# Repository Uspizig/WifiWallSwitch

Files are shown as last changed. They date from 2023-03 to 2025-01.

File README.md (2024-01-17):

A WallSwitch with a clever EINK Display that measures your Air Quality, measures Temperature, detects movement, measures Light Conditions... and many more.
And the Best of all: "It can be your own LOCAL Voice Assistant or MediaPlayer"

This Device perfectly integrates in your Smart Home (e.g. HomeAssistant or IO Broker).  
No permanent backlight On Display that disturbs your sleep. Just a brillant E-Ink Display with outstanding contrast and some Buttons that you can feel when you swipe over with your plam.
A lightweight Design with a perfect WAF Factor. Fits on your Desktop or on your wall. 
The device can be programmed, adapted, hacked, tinkered and individualised by YOU.
You want to push boundries even further: Use Arduino and do a deep Dive in Ultra Low Power Mode. The Battery might run for Years with an intelligent Power Gateing.

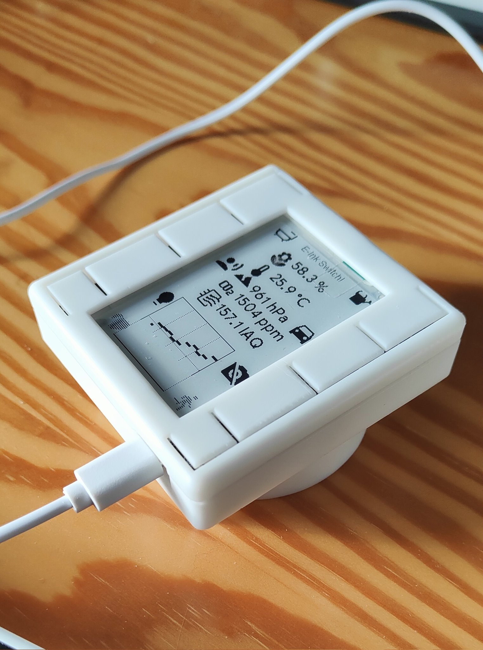
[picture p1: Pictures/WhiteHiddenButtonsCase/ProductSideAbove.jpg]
Side View of WifiWallSwitch with EINK Screen and Design Buttons. Ambient Light OFF Product View of WifiWallSwitch with disabled RGB LEDs


Eight Ambient Light LEDs can give you a visual quick feedback if needed:
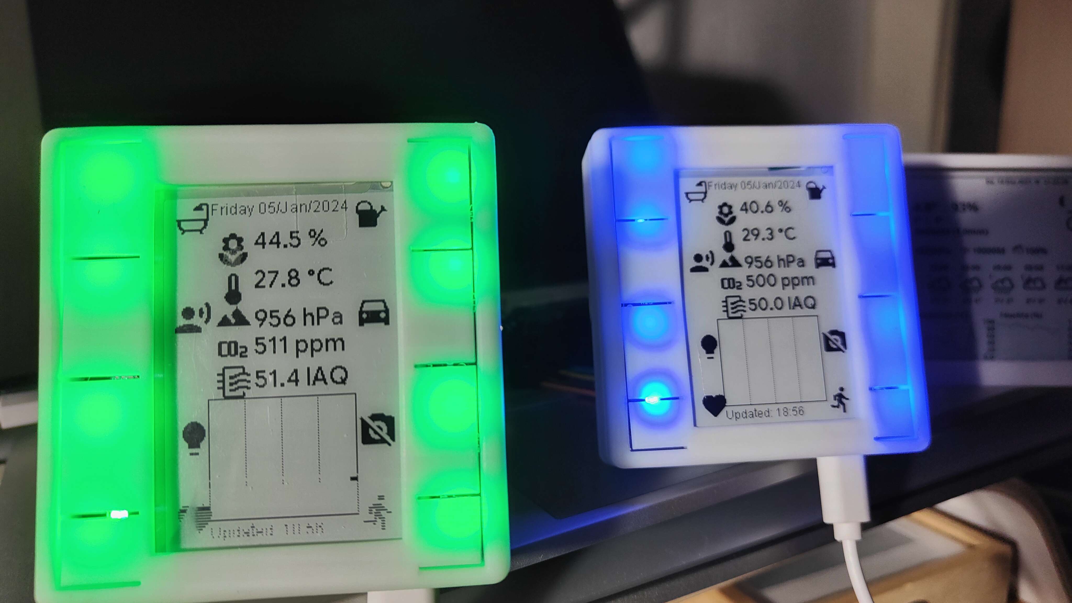
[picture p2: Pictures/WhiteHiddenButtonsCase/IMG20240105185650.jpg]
Side View of WifiWallSwitch with EINK Screen and Design Buttons. Ambient Light ON Product View of WifiWallSwitch with enabled RGB LEDs


View of the components in HomeAssistant
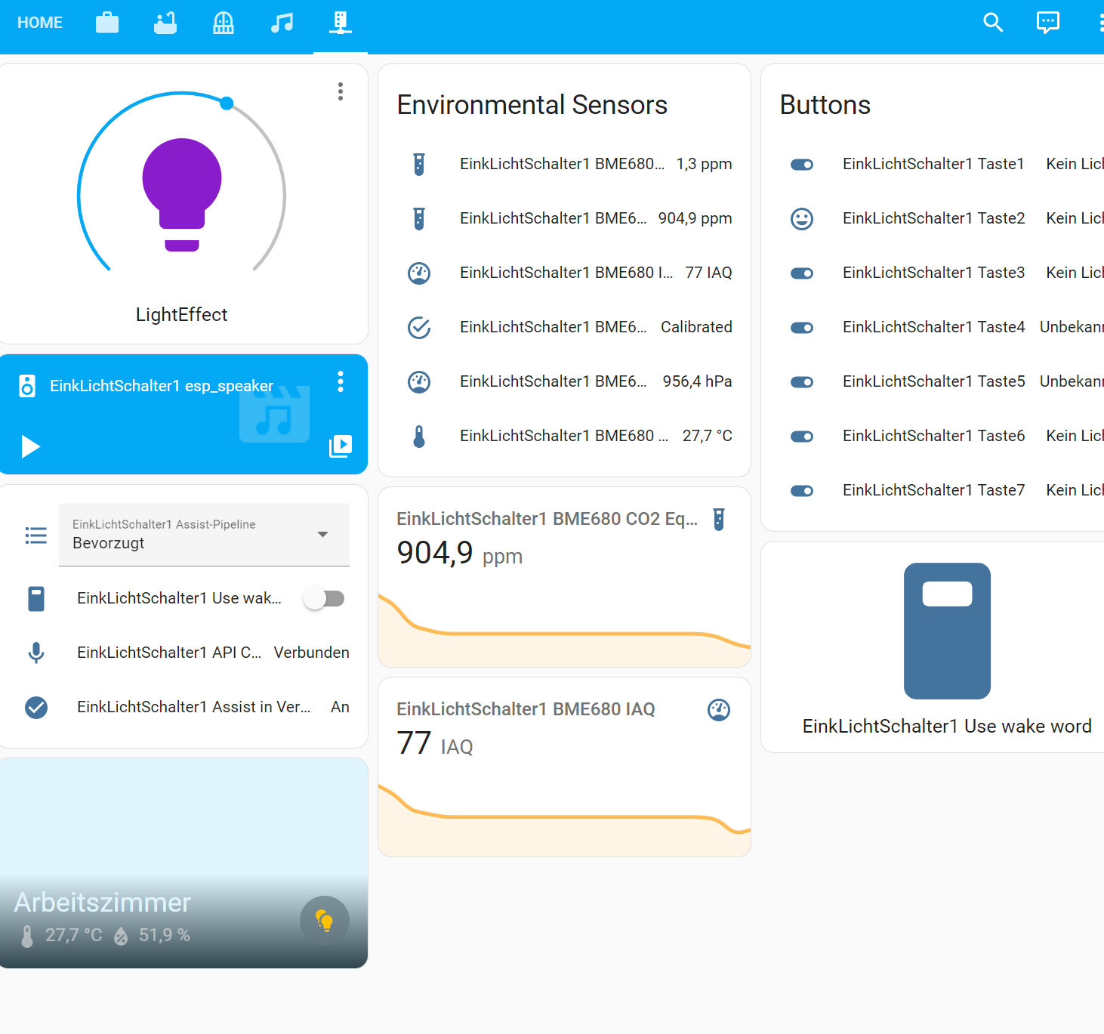
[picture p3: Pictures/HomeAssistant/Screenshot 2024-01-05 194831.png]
Side View of WifiWallSwitch with EINK Screen and Design Buttons. Ambient Light ON Product View of WifiWallSwitch with enabled RGB LEDs


What is under the hood:
Main thing you see when you have a first look is the massive 2.7 " E-Ink Screen
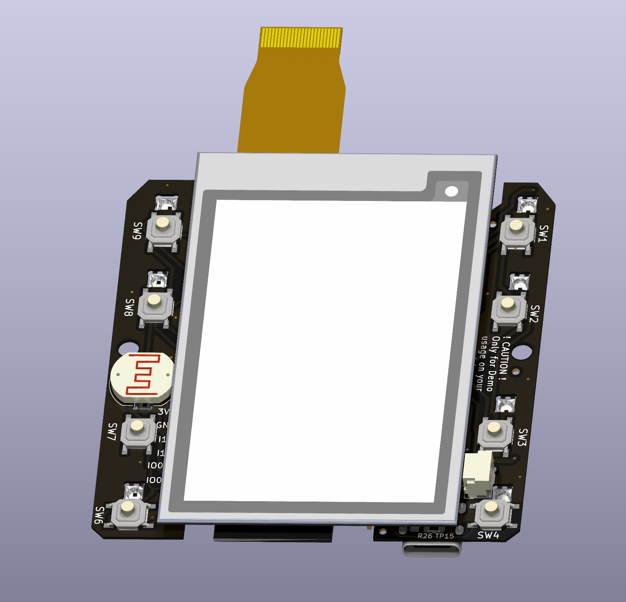
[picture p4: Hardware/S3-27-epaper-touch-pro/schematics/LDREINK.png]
Customer VIEW of PCB of WifiWallSwitch WiFiWallSwitch Customer side


See it in Action here: https://twitter.com/USpizig/status/1747731234338336940

Hardware Specs:
- 2.7" EInk Epaper with or without Touch Screen... other screens might work as well
- ESP32 S3 Dual Core Microcontroller with USB OTG, Wifi & BT, Mass Storage Mode. 
- 8 X SK6812 Mini RBG LEDs
- 8 X Hardware Buttons...REAL BUTTONS with clicks: No Touch Buttons that might not work if you have wet or dirty fingers
- BOSCH BME680 for eCo2, Temperature, Humidity and Pressure Measurements
- ST LSM6DSL Ultra Low Noise MEMS Gyro + Accel for Movement Detection and Earthquake Detection
- INMP441 MEMS Microphone for Voice Assistant
- Socket for MAX98357A I2S Class D Amplifier for Audio Output for Media Player
- LDR Ambient Light Sensor: Detect the Ambient Light conditions in your room.
- RTC1: TPL5110 for PowerGateing and low Standby Current
- RTC2 Option: RV3028 C7 for Ultra Low RTC with Backup Cap lasts 3h
- Optional: RFM95 LoRa Radio for Desaster Radio (Limitations: May not work together with Microphone)
- Connector for KNX EIB Smart Home with Nano BCU
- Connector for Your Own Ideas... Several free GPIOs
- Switch for adapting to Waveshare/Gooddisplay EINK Display
- All SMD components have a size 0603 or larger to enable easier soldering/Tinkering.

Underneath the EINK Screen is a placeholder for an optional RFM95/RFM98 Long Range Communication Module. This Module works with LoRa, FSK or other wireless standards. 
Up 15km Range of communication can be established with this module. Perfect as well for decoding your Bresser Weather Station and translate it to MQTT for your Smart Home.

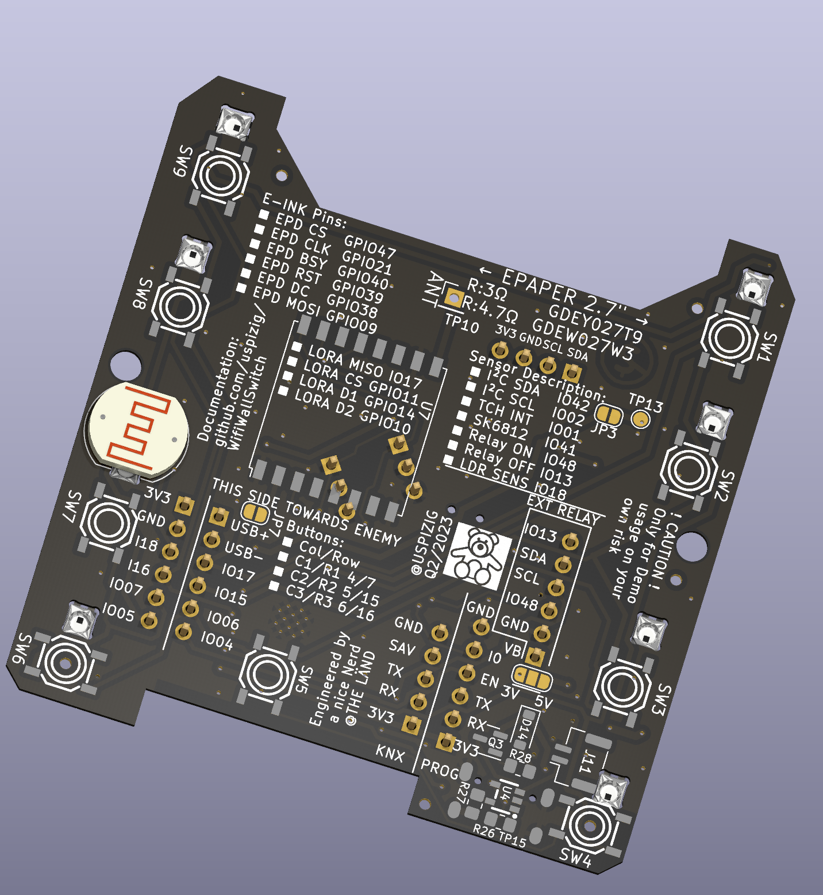
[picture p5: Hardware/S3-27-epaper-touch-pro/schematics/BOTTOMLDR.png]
PCB Customer View of WifiWallSwitch without EINK Screen


The other side of the PCB looks like this:
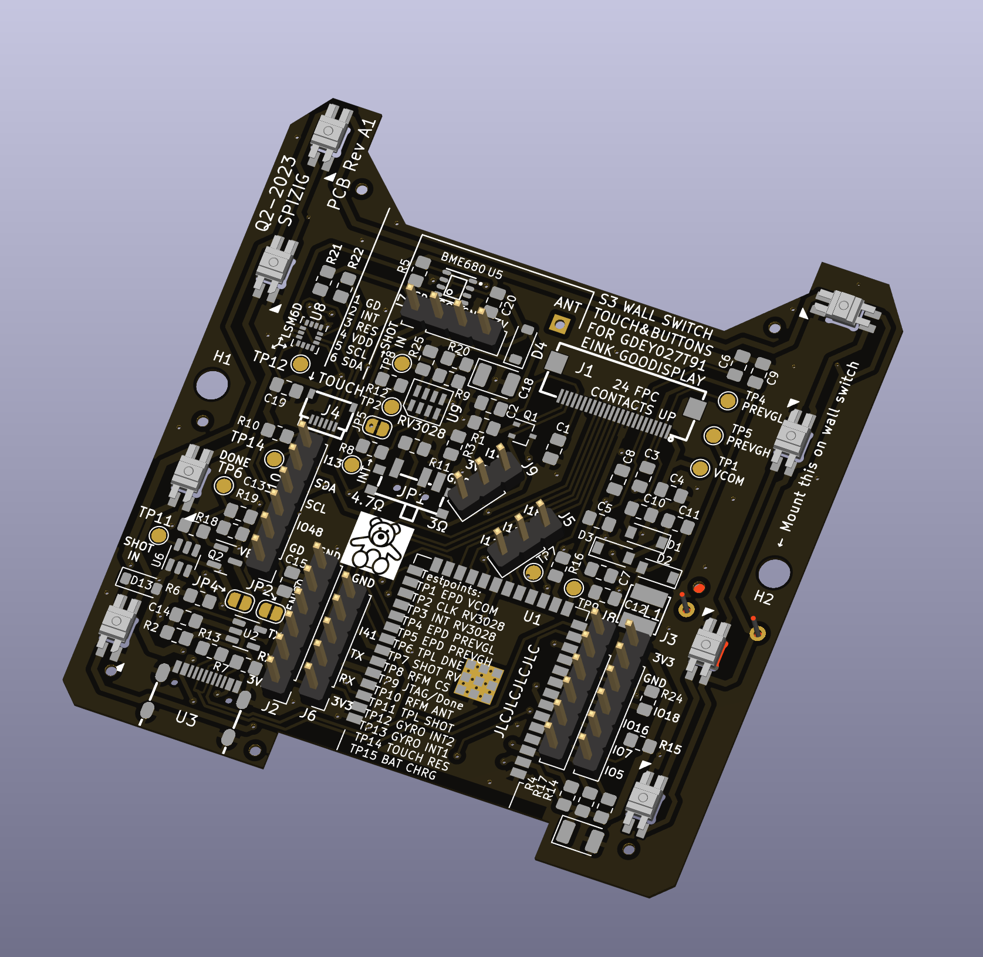
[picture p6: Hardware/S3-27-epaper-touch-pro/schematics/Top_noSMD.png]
Parts view of PCB without SMD parts soldered


If you scroll further down you may see a picture of the TOP View of the PCB
On the Top side of the PCB you see the Main Processor: This is an ESP32-S3 and various sensors:
- Ultra Low Power RTC RV3028 [U9] for Low Power Battery Operation wakeup
- Ultra Low Noise MEMS LSM6DSL [U8] 6 Axis GYRO+ACCEL + Tap Detection
- Ultra Low Power Gateing Chip TPL5110: [U6]
- Bosch BME680 for Air Quality Measurements [U5]
- EInk Screen connector 
- Touch Screen connector [JP5]
- Space for the oprional INMP441 Microphone [J5], [J9]
- 8 RGB LEDs which can be adressed individually. Perfect for Quizshow effects. Ideal for Audiovisual feeddback
- 9 Click Buttons. [SW1-SW9] - SW5 is hidden under the screen and can be used as Physical Click Button
- Space for Several Connectors[J2, J8, J3] to plugin even more modules like Audio Module for an Media Player or Voice Assistant Feedback.

And another view with all the SMD Parts simulated:
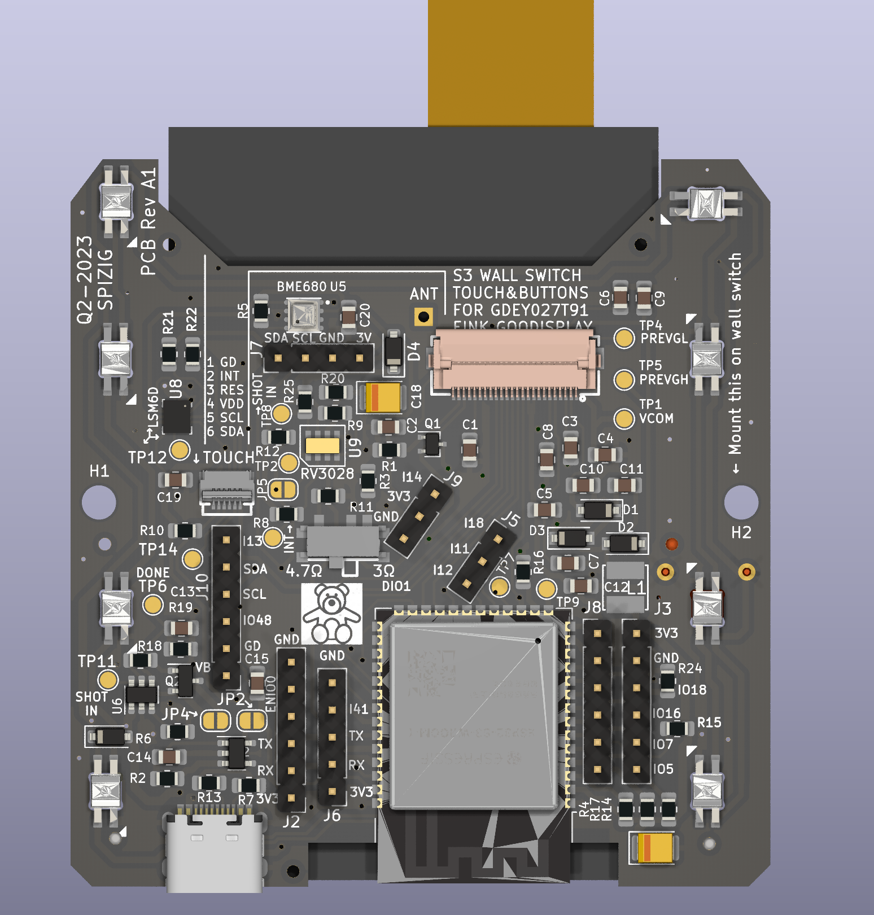
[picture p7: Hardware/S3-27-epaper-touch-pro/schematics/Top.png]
TOP PCB View of WifiWallSwitch


What is currently working:

Hardware:
- Currently the HW BringUp is about to finish.
- The basic Hardware is up and running stable.
- Eink, Microphone, LEDs, Buttons, BME680. LSM6 Gyro work well.

The optional Modules are  still under test
  -   TP4065 Lipo Battery Charger Circuit
  -   Battery Switchover Circuit once Battery is fully charged to avoid Battery damage due to overcharging
  -   TPL5110 Low Power RTC Module
  -   RV3028 Low Power Module
  -   Long Range Communication Module RF Module RFM95
  -   230V Power Converter to 5V/3.3V for Wall Mode.

Software Sketches working:
Arduino:
  - Flashing the Device over USB with you Chrome Web Browser: https://web.esphome.io/
  - Logging over USB USBSerial
  - EInk Basic Update of content
  - EInk Partial Update Dynamic Update of content
  - Read out BME680 Data (Temp, Humidity, Pressure, eCO2, IAQ,...)
  - Microfone: Calculate loudness in dBA
  - Audio Player: Playback MP3, TTS via Google and Webradio
  - 8 Buttons can be detected.
  - 8 RGB LEDS whcih can be adressed individually
  - LSM6 Gyro: Read out of Basic Values Roll, Pitch, Yaw
  - All typical 24pin EInk Displays which are mentioned on GxEPD2: https://github.com/ZinggJM/GxEPD2/tree/master
  - Flashing & Logging the Device over 2.54mm Socket with a dedicated Flash Adapter

 Home Assistant with ESPHome Integration:
   - Flashing the Device over USB with you Chrome Web Browser: https://web.esphome.io/
   - Logging over USB with ESP Home
   - Display Messages on EInk Display
   - Voice Assistant: Switch on Light,.... you name it
   - Media Player: Playback of TTS Messages, Audio Files,Web Radio
   - Keyboard: 8 Buttons are detected individulally
   - RGB LED Control SK6812 Mini
   - Flashing & Logging the Device over 2.54mm Socket with a dedicated Flash Adapter
     
Known ESPHome Issues right now:
  - Voice Assistant has some issues if used together with Media Player. Leads to Stuttering Audio once Media Playback is started.
  - No LSM GYRO integration
  - 2 GPIOS used to much due to Keypad component of ESPhome only supports 4x4 Matrix Keyboards
  - GPIO8 can not be used for Keyboard Fake Keys.

Known Issues on Arduino:
  - LSM6 Gyro has some issues with BME680 BSEC: Leads to constant output of 500 ppm

What is planned:
- EInk Touch Screen 2.7 'integration of Good Display https://www.good-display.com/product/259.html
- A Touch screen https://www.good-display.com/product/259.html
- Read out data of a Weather Station Bresser 6in1 We<ther Station and forward to MQTT with an RFM95 Chip.
- LDR for Light Detection. Monitoring of Enviroment Data
- Ultra Low Power RTC RV3028 for Low Power Battery Operation wakeup
- Ultra Low Noise MEMS LSM6DSL GYRO+ACCEL for Earthquake Detection-> https://github.com/biagiom/QuakeSense
- Ultra Low Noise MEMS LSM6DSL for movement detection and Tap Detection
- Ultra Low Power Mode TPL5110: Let the Processor sleep with TPL5110 Power Gateing and shut down all that is battery draining.
- Bosch BME680 for Air Quality Measurements
- 9 physical buttons for moments where you do not wnat to use a touchscreen
- KNX Integraion with Nano BCU
- LORA:
  - Transmit Air Quality Data on a regular Basis (every 15min)
  - Transmit Data when Air Quality changes dramatically
  - Transmit Data when Air Quality changes dramatically
  - Recieve Commands to Switch on / off ext Relay
  - Switch to Desaster Mode and search for BLE Heart Rate Devices nearby and sent this data via LoRa

WARNINGS
This is my hobby. Please do NOT be a DIRTY COPY CAT and make your own comercial product out of it.
See License before you copy anything out of it.
 
If you use this Hardware, Software, Code or schematics you agree that any harm, damage, burn or injuries are YOUR RESPONSIBILITY! 
The Author may not be held liable for any damage that might happen if you try this code out or use this product or parts of it.
Legal validity of this disclaimer: This disclaimer is to be regarded as part of the internet publication which you were referred from. 
If sections or individual terms of this statement are not legal or correct, the content or validity of the other parts remain uninfluenced by this fact.

Referrals and links The author is not responsible for any contents linked or referred to from his pages - unless he has full knowledge of illegal contents and would be able to prevent the visitors of his site from viewing those pages. If any damage occurs by the use of information presented there, the author might not be liable. Furthermore the author is not liable for any postings or messages published by users of discussion boards, guest books or mailing lists provided.

Arduino:
Before you compile please ensure you modify all your credentials and used sensors in "credentials.h" which have been marked REPLACEMEUSER
This Source Code is provided "AS it is" . 
Also ensure you have installed the following libs:
Code Sources that influenced this Source Code and which libaries you may need:

https://github.com/knolleary/pubsubclient/blob/master/examples/mqtt_auth/mqtt_auth.ino
https://randomnerdtutorials.com/esp32-mqtt-publish-subscribe-arduino-ide/
RGBW for SK6812:
Original code by Jim Bumgardner (http://krazydad.com).
Modified by David Madison (http://partsnotincluded.com).
Extended by Christoph Wempe
https://gist.github.com/CWempe?direction=desc&sort=created

Adafruit BME/BMP280/SGP30 sketches/libs
Please consider buying their products due to their great work in Arduino libs
https://github.com/adafruit/Adafruit_SGP30
https://github.com/adafruit/Adafruit_BMP280_Library

Bosch BME680 BSEC Lib
https://github.com/BoschSensortec/BSEC-Arduino-library

Andreas Spiess
OTA Sketch for OTA Update of the ESP32 over Wifi
https://github.com/SensorsIot/ESP32-OTA

Knolleary pubsubclient
/pubsubclient/blob/master/examples/mqtt_auth/mqtt_auth
https://github.com/knolleary/pubsubclient

Fastled
https://github.com/FastLED/FastLED

Settings for Jumpers & Solder Bridges:
Jumper:
- JP2 = This MUST BE OPEN! if USB Connected & 3.3V Prog
- JP3 = GYRO INT Emergency CUT: If you want no more Interupts from the Gyro.
- JP4 = MAINS Mode / No TPL5110 Mode. Disable the RTC for Power Gateing. Use for permanent connection to USB
- JP5 = RV3028 INT CUT for RFM95 OP. Must be cut if an RFM Long Range RF Mode is installed
- JP6 = Switch of Input Power Supply Voltage
- JP5 = Solder for RFM95 OP & Cut JP5

I²C Address of onboard Devices.
- 0x52 RV3028
- 0x6A LSM6DSL
- 0x77 BME680

Testpoints for soldering and Tinkering:
TP1 EPD VCOM -> Debuging of EINK
TP2 CLK RV3028 
TP3 INT RV3028
TP4 EPD PREVGL -> Debuging of EINK
TP5 EPD PREVGH -> Debuging of EINK
TP6 TPL DNE -> Debuging of EINK... Connect to a GPIO for Ulatra Low Power sleep and fire a 1 whenever you want to Deep Sleep on that GPIO
TP7 SHOT RV3028 -> Wakeup Pin for RTC2
TP8 RFM CS -> Soldering Pin needed for RFM95
TP9 JTAG/Done
TP10 RFM ANT -> Connector for 868 MHZ Antenna
TP11 TPL SHOT -> Wakeup Pin for TPL 5110 RTC
TP12 GYRO INT2
TP13 GYRO INT1
TP14 TOUCH RES -> Touch Controller Reset Pin. Hopefully never needed
TP15 BAT CHRG -> Battery charg Pin. Hopefully never needed.

Known HW Limitations:
- LDR is not working when WIFI is ON. Stupid ESP32-S3 Limitations ADC2 is not working if WIFi is on
- HW Buttons placed 90° wrong. Wrong Pinout matching

TODO:
- RV_3028 INT ist connected with LORA RFM MISO. No paralell usage possible
- INMP441 Mic ist connected with LORA RFM95. No paralell usage possible
- USB ESD Diodes missing
- SK6812 is an input of KNX connector at the same time?
- Rerouting of SK6812 necesssary. Not possible to  GPIO 0... otherwise board will not start.
- Done Pin TPL5110 not routed to ESP32 IO3. No Power Shutdown without a Solder Bridge
-

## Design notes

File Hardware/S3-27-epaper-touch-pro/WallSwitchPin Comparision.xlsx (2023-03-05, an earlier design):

PIN ESP32 S3 | PIN ESP32 | Function | ADC ESP32-S3 | ESP32
IO4 | IO36 | COL1 | ADC1 CH3 | ADC1 CH0
IO5 | IO39 | COL2 | ADC1 CH4 | ADC1 CH3
IO6 | IO34 | COL3 | ADC1 CH5 | ADC1 CH6
IO7 | IO35 | ROW1 | ADC1 CH6 | ADC1 CH7
IO15 | IO32 | ROW2 | ADC2 CH4 | ADC1 CH4
IO16 | IO33 | ROW3 | ADC2 CH5 | ADC1 CH5
IO17 | IO25 | MISO RFM95
IO18 | IO26 | Connector,
IO8 | IO27 | RTC_INT, GYRO INT
IO19 | IO14 | USB
IO20 | IO12 | USB
IO3 |  | UNUSED | STRAPING | NO USE
IO46 | GND | UNUSED | STRAPING | NO USE
IO9 | IO13 | MOSI EPD/RFM
IO10 | SHD | RFM95 DIO2 |  | NO USE
IO11 | SWP | RFM_CS |  | NO USE
IO12 | SCS | RFM95 DIO1 |  | NO USE
IO13 | SCK | RELAIS OFF |  | NO USE
IO14 | SDO | RFM95 RES |  | NO USE
IO21 | SD1 | EPD CLK |  | NO USE
IO47 | IO15 | EPD CS
IO48 | IO2 | Relais ON |  | STRAPING
IO45 |  | unused | STRAPING | NO USE
IO0 | IO0 | unused | STRAPING | STRAPING
IO35 | IO4 | unused | STRAPING
IO36 | IO16 | unused | STRAPING
IO37 | IO17 | unused | STRAPING
IO38 | IO5 | EPD_DC |  | STRAPING
IO39 | IO18 | EPD_RST
IO40 | IO19 | EPD_BUSY
IO41 | NC | SK6812_DATA
IO42 | IO21 | TOUCH_SDA
RX | RX
TXD0 | TXD0
IO2 | IO22 | Touch_SCL
IO1 | IO23 | Touch_INT

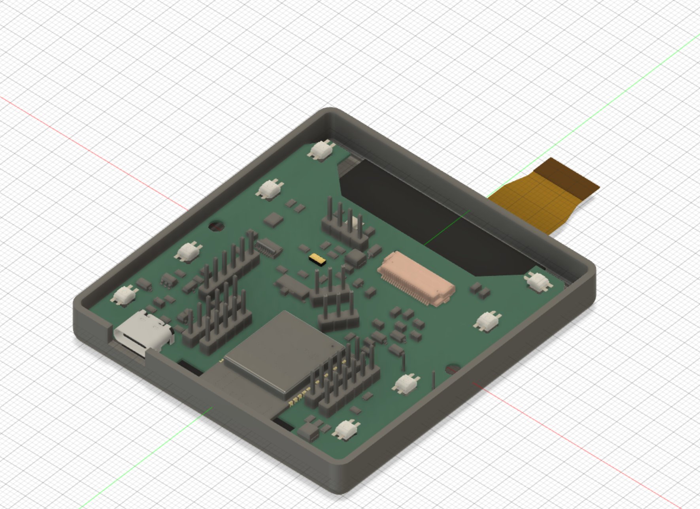
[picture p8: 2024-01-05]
Pictures/KiCad3DView/case bot.jpg

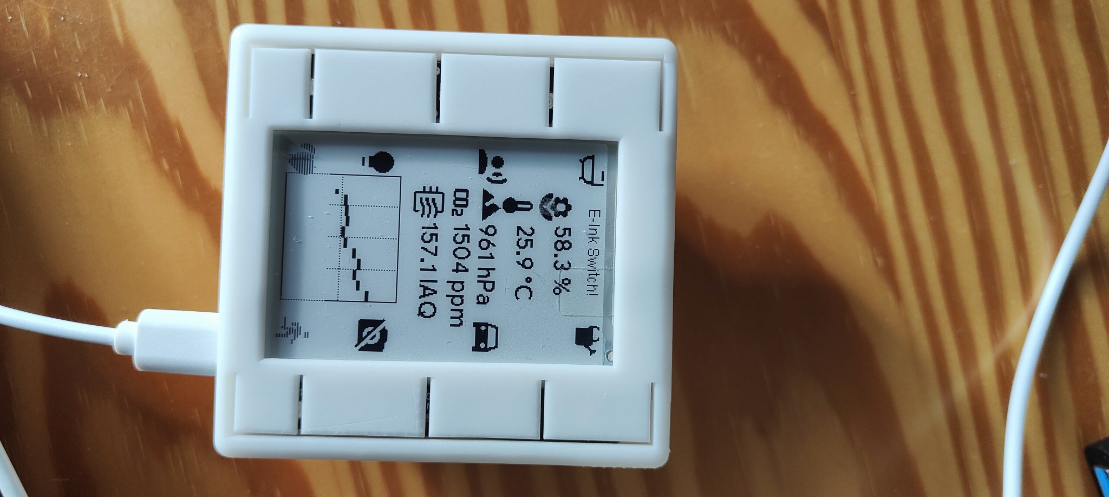
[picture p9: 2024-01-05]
Pictures/WhiteHiddenButtonsCase/topview.jpg

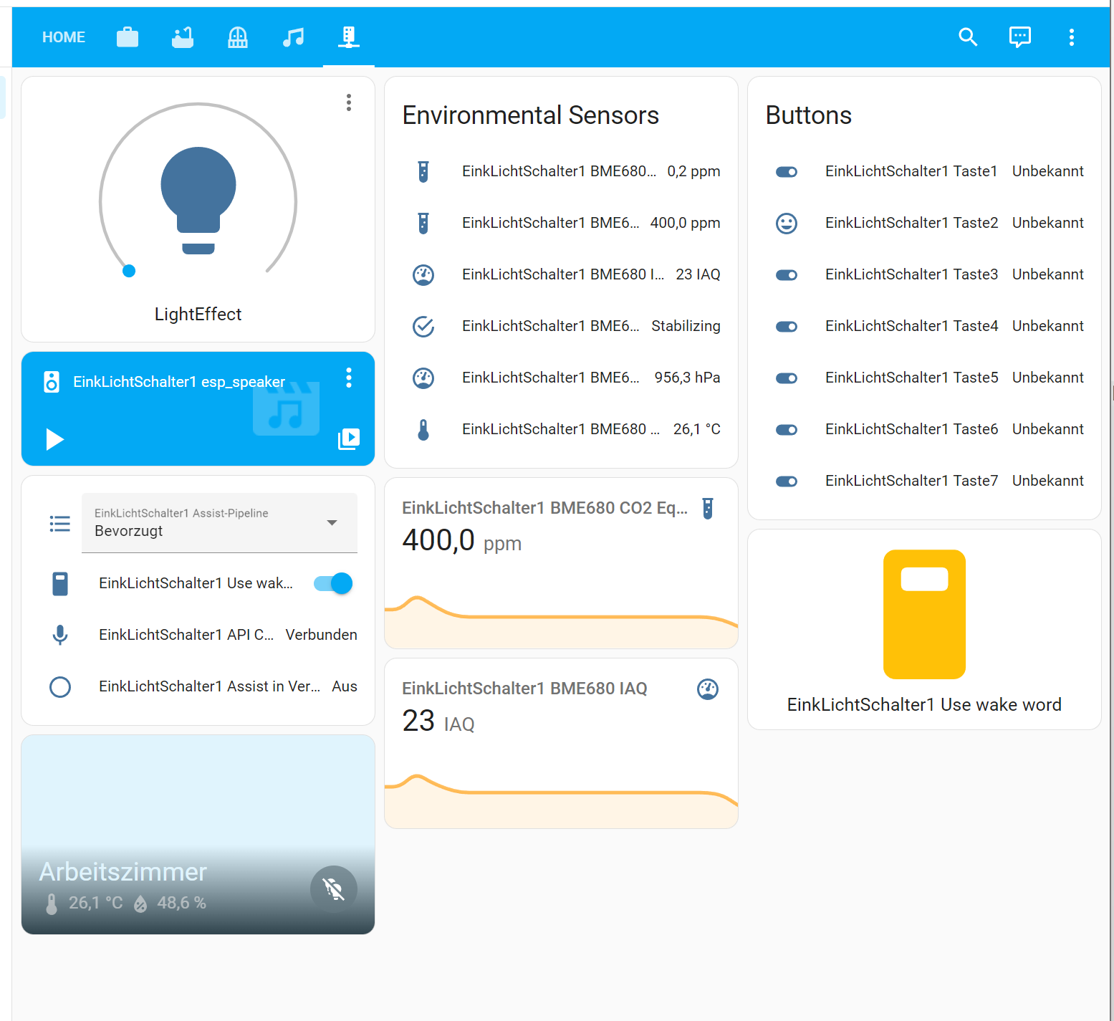
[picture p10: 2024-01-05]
Pictures/HomeAssistant/Screenshot 2024-01-05 184331.png

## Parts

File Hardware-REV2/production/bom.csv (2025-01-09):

Designator | Footprint | Quantity | Value | LCSC Part #
AE1 | U.FL_Molex_MCRF_73412-0110_Vertical | 1 | Antenna_Shield
C1, C14, C15, C16, C17, C2, C3, C4, C5, C6, C7, C8 | 0805 | 12 | 1uF | C28323
C10, C11, C12, C9 | 0805 | 4 | 4.7uF 50V_US | C162420
C13, C19, C20 | 0805 | 3 | 100nF | C49678
C18 | CP_EIA-3528-21_Kemet-B | 1 | 220uF
C21, C22, C26 | 0805 | 3 | 100nF
C23 | 0805 | 1 | 4u7F
C24 | 0805 | 1 | 220nF
C25 | 0603 | 1 | 100nF
D1, D13, D14, D2, D3, D4 | D_SOD-123 | 6 | MBR0530
D10, D11, D12, D5, D6, D7, D8, D9 | MX_SK6812MINI-E | 8 | SK6812MINI-E
H1, H2 | MountingHole_3.2mm_M3 | 2 | MountingSwitch
J1 | FPC-SMD_P0.50-24P_QCHF-SM-H2.0 | 1 | AFC24-S24FIC-00 | C262292
J10 | PinHeader_1x02_P2.00mm_Vertical | 1 | Conn_01x02_Pin
J11 | JST_GH_SM02B-GHS-TB_1x02-1MP_P1.25mm_Horizontal | 1 | Conn_01x02_Pin
J12 | PinHeader_1x07_P2.54mm_Vertical | 1 | Conn_01x07_Pin
J13 | TF-SMD_XKTF-0803-0 | 1 | Micro_SD_Card_Det_US
J2, J3, J8 | PinHeader_1x06_P2.54mm_Vertical | 3 | Conn_01x06
J4 | FFC-SMD_6P-P0.50_FH34SRJ-6S-0.5SH | 1 | TochConn | C224194
J5, J9 | PinHeader_1x03_P2.54mm_Vertical | 2 | Conn_01x03_Pin
J6 | PinHeader_1x05_P2.54mm_Vertical | 1 | Conn_01x05_Pin
J7 | PinHeader_1x04_P2.54mm_Vertical | 1 | Conn_01x04_Pin
JOG | JogWheel | 1 | jogdial
JP1 | SW-SMD_G-SWITCH_MK-12C02-G015 | 1 | RESE | C2911519
JP10 | SolderJumper-2_P1.3mm_Bridged_RoundedPad1.0x1.5mm | 1 | Jumper_2_Open
JP11, JP2, JP3, JP5 | SolderJumper-2_P1.3mm_Bridged_RoundedPad1.0x1.5mm | 4 | Jumper_2_Bridged
JP12, JP14, JP4, JP8 | SolderJumper-2_P1.3mm_Open_RoundedPad1.0x1.5mm | 4 | Jumper_2_Open
JP13, JP9 | SolderJumper-2_P1.3mm_Open_RoundedPad1.0x1.5mm | 2 | Jumper_2_Bridged
JP6, JP7 | SolderJumper-3_P1.3mm_Bridged12_RoundedPad1.0x1.5mm_NumberLabels | 2 | Jumper_3_Bridged12
L1 | IND-SMD_L4.0-W4.0 | 1 | 10uH
Q1 | SOT-323_SC-70 | 1 | Si1308
Q2, Q3 | SOT-23 | 2 | Si2301
R1, R10, R12, R14, R15, R17, R18, R19, R2, R25, R28, R4, R5, R8, R9 | 0805 | 15 | 10K | C17414
R11, R40 | 0805 | 2 | 0.47R
R13, R27, R7 | 0805 | 3 | 5k11 | C27834
R16, R24, R29, R30 | 0603 | 4 | N.C.
R20 | 0805 | 1 | N.C.
R21, R22 | 0805 | 2 | 0R | C17477
R23 | R_LDR_10x8.5mm_P7.6mm_Vertical | 1 | LDR03
R26 | 0805 | 1 | 800K
R3 | 0805 | 1 | 3R
R31 | 0805 | 1 | 100K
R32 | 0805 | 1 | 330k
R33 | 0603 | 1 | 100K
R34, R35, R36, R37, R38, R39 | 0603 | 6 | 10k
R6 | 0805 | 1 | 220K
SW1, SW2, SW3, SW4, SW5, SW6, SW7, SW8, SW9 | SW-SMD_4P-CORR-L5.2-W5.2-P3.70-LS6.4 | 9 | SW_Push
TP1, TP13, TP7, TP9 | TestPoint_Pad_D1.5mm | 4 | VCOM
TP10 | PinHeader_1x01_P2.54mm_Vertical | 1 | VCOM
TP11 | TestPoint_Pad_D1.5mm | 1 | SHOT
TP12 | TestPoint_Pad_D1.0mm | 1 | VCOM
TP14 | TestPoint_Pad_D1.5mm | 1 | RESET_TOUCH
TP15 | TestPoint_Pad_D1.0mm | 1 | M-
TP16 | TestPoint_Pad_D1.0mm | 1 | M+
TP2 | TestPoint_Pad_D1.5mm | 1 | CLKOUT
TP3 | TestPoint_Pad_D1.5mm | 1 | SHOT1
TP4 | TestPoint_Pad_D1.5mm | 1 | PREVGL
TP5 | TestPoint_Pad_D1.5mm | 1 | PREVGH
TP6 | TestPoint_Pad_D1.5mm | 1 | DONE
TP8 | TestPoint_Pad_D1.5mm | 1 | SHOT IN
U1 | ESP32-S3-WROOM-1 | 1 | ESP32-S3-WROOM-1-N8
U10 | TQFN-16_L3.0-W3.0-P0.50-BL-EP1.5 | 1 | MAX98357
U11 | LGA-16_3x3mm_P0.5mm | 1 | MMC5883MA
U12, U14 | SW-SMD_SIQ-02FVS3_1 | 2 | SIQ-02FVS3
U13, U16 | Bosch_LGA-8_2.5x2.5mm_P0.65mm_ClockwisePinNumbering | 2 | BME280
U15 | ZMOD4410AI1V | 1 | 4410AI1V
U17 | HVSSOP-10-1EP_3x3mm_P0.5mm_EP1.57x1.88mm | 1 | DRV8830DGQR
U2 | SOT-23-5 | 1 | RT9013 | C47773
U3 | USB-C_SMD-TYPE-C-31-M-12 | 1 | KoreanHropartsElecTYPE-C-31-M-12 | C165948
U4 | SOT-23-5_L3.0-W1.7-P0.95-LS2.8-BR | 1 | TP4065 | C113540
U5 | LGA-8_L3.0-W3.0-P0.80-TR | 1 | BME680 | C125972
U6 | SOT-23-6 | 1 | TPL5110 | C125830
U7 | HOPERF_RFM9XW_SMD | 1 | RFM95W-868S2 | C2844472
U8 | LGA-14_3x2.5mm_P0.5mm_LayoutBorder3x4y | 1 | LSM6DSOWTR | C2829074
U9 | rv3028 | 1 | RV3032

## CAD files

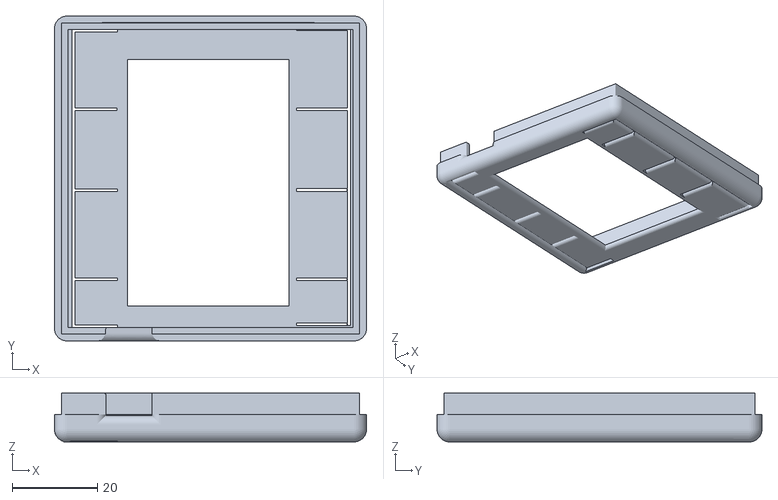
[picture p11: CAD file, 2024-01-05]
CaseSTL/GehaeuseSchlitzV2.stl
73.4 x 76.4 x 11.5

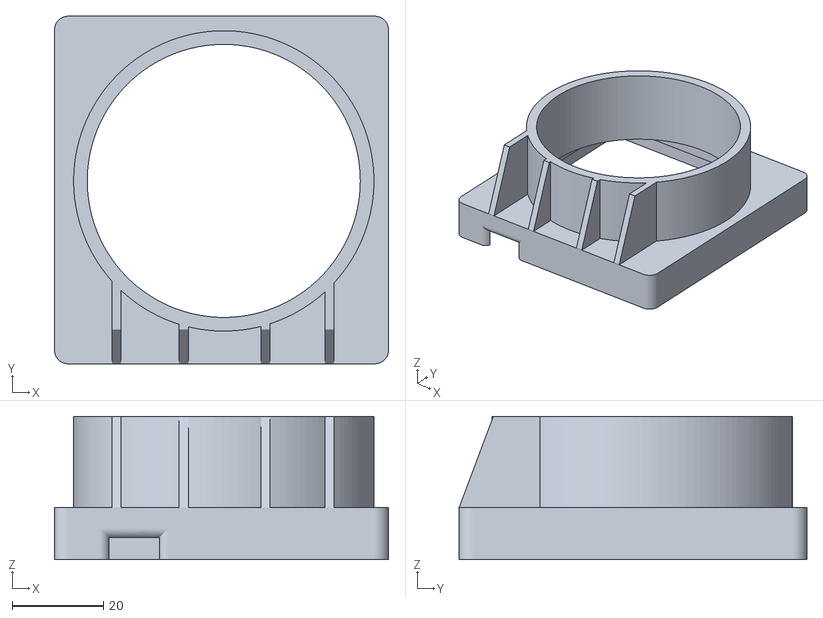
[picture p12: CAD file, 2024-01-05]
CaseSTL/Laut.stl
73.4 x 76.4 x 31.5

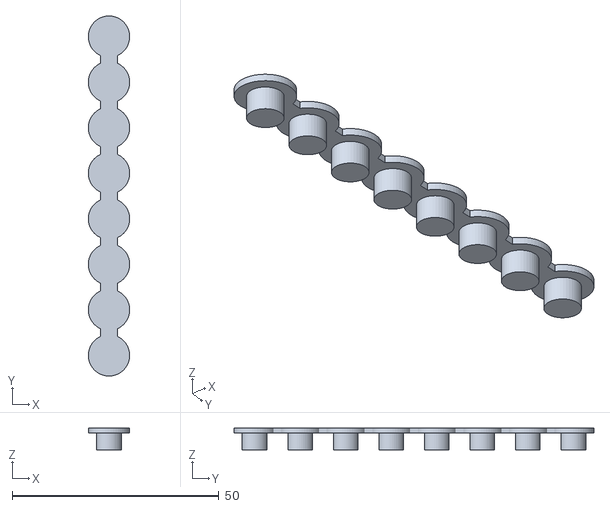
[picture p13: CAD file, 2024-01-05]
CaseSTL/taster3.stl
10.0 x 87.0 x 5.20

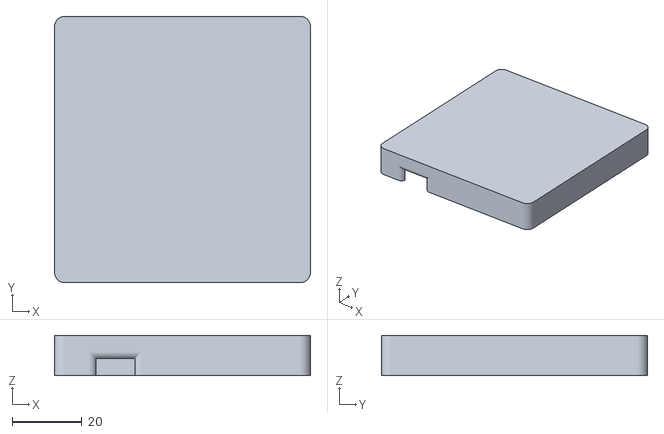
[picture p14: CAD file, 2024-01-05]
CaseSTL/bodenOhneLoch.stl
73.4 x 76.4 x 11.5

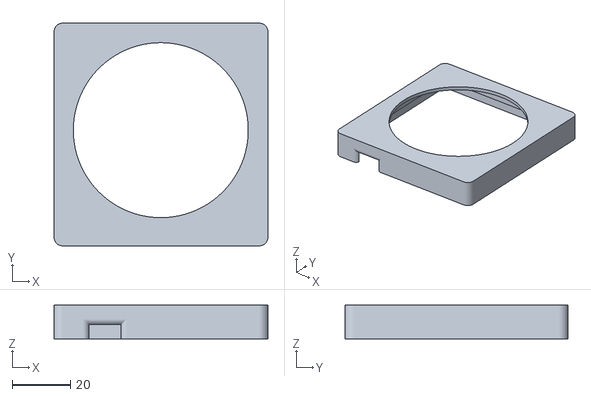
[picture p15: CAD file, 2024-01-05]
CaseSTL/bodenMitLoch.stl
73.4 x 76.4 x 11.5

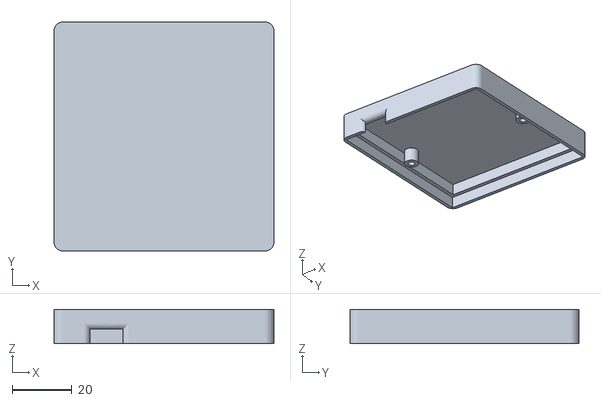
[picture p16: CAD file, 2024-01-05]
CaseSTL/boden_bohrung.stl
73.4 x 76.4 x 11.5

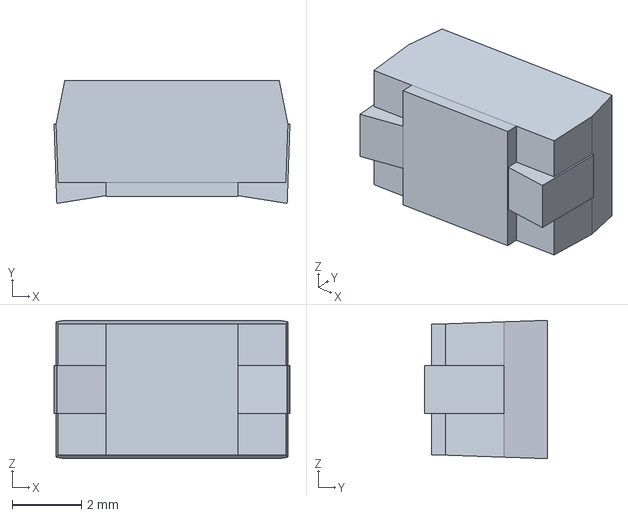
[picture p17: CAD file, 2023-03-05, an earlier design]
Hardware/S3-27-epaper-touch-pro/parts/3d/c-5-1676966-1-ba-3d.stp
6.82 x 3.55 x 4.00 mm

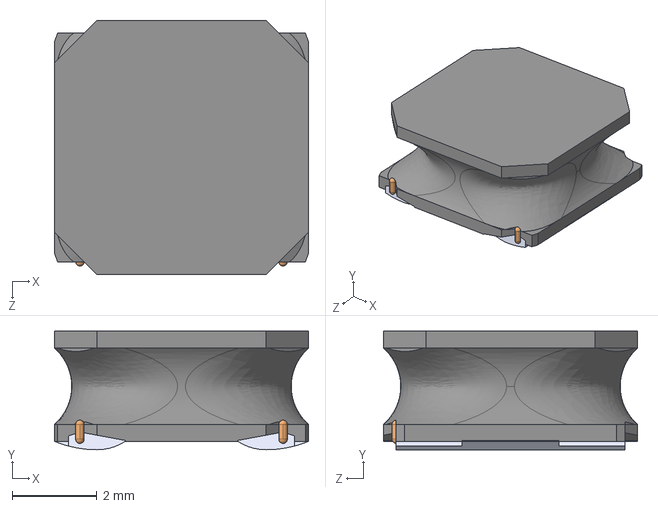
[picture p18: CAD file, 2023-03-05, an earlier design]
Hardware/S3-27-epaper-touch-pro/parts/3d/L-40xx.STEP
6.00 x 2.80 x 6.00 mm

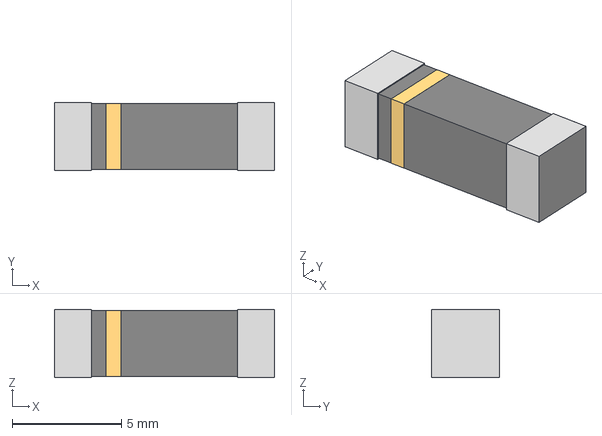
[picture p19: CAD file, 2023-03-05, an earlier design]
Hardware/S3-27-epaper-touch-pro/parts/3d/0443Series_LTF.step
10.1 x 3.12 x 3.12 mm

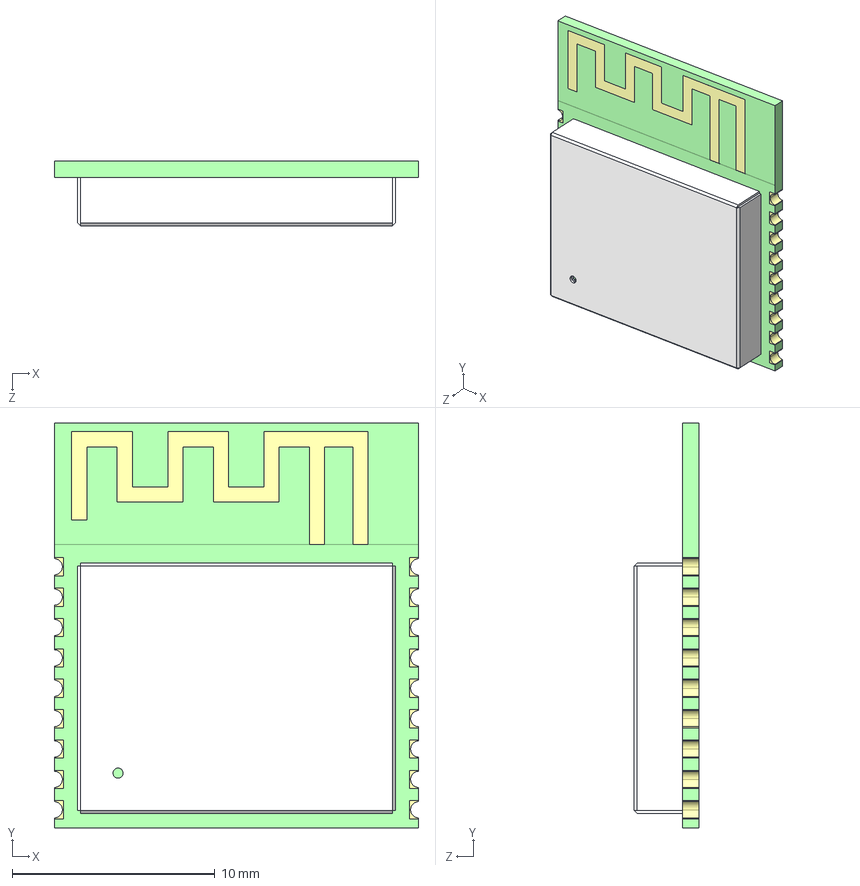
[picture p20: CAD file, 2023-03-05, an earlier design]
Hardware/S3-27-epaper-touch-pro/parts/3d/ESP32-C3-WROOM-02-H4.step
18.0 x 20.0 x 3.20 mm

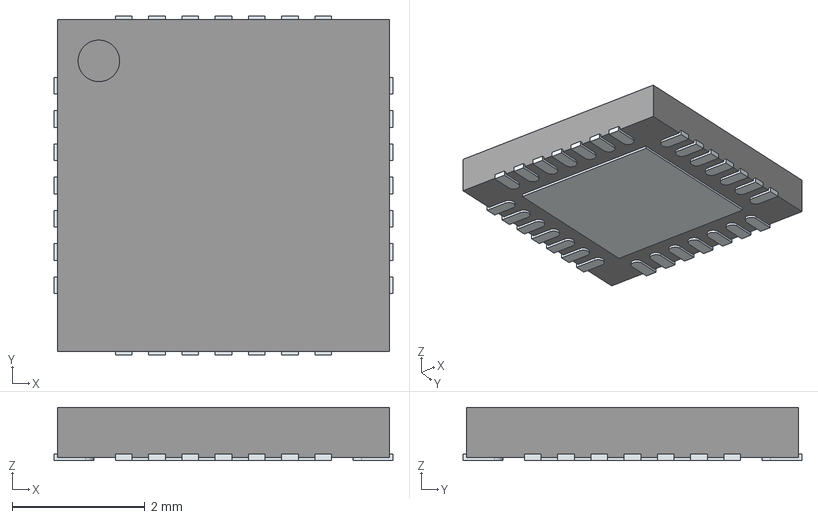
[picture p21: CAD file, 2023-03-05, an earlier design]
Hardware/S3-27-epaper-touch-pro/parts/3d/CP2102N-A02-GQFN28R.step
5.10 x 5.10 x 0.8 mm
ThermalPin
PinsArrayLR
PinsArrayTB

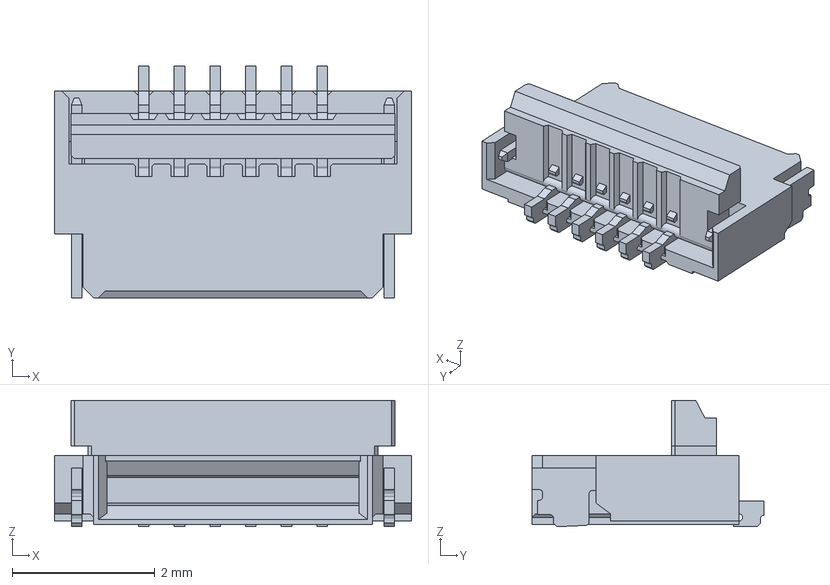
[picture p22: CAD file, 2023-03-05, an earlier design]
Hardware/S3-27-epaper-touch-pro/parts/3d/FH34SRJ-6S-0.5SH50-Hirose.step
5.00 x 3.25 x 1.77 mm

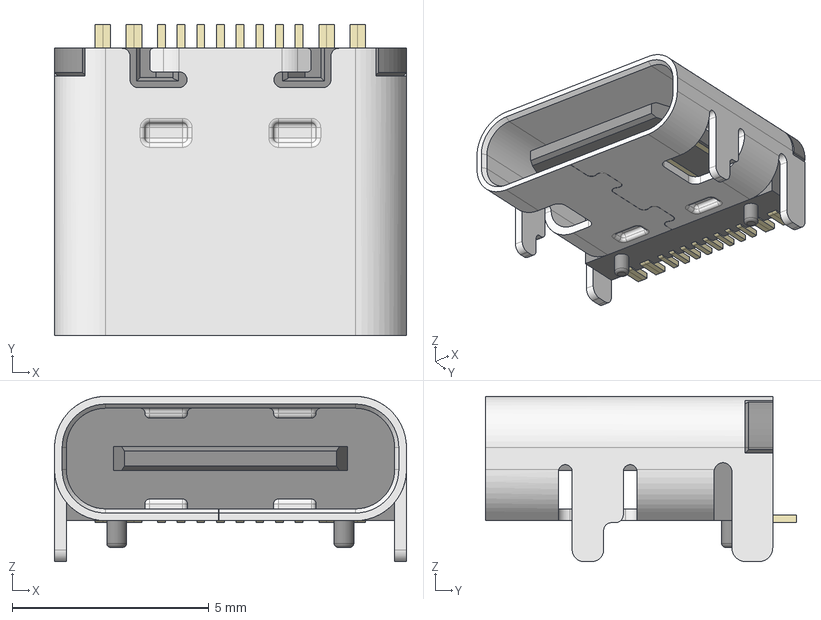
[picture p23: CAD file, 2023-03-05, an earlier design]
Hardware/S3-27-epaper-touch-pro/parts/3d/HRO_TYPE-C-31-M-12.step
8.95 x 7.90 x 4.20 mm

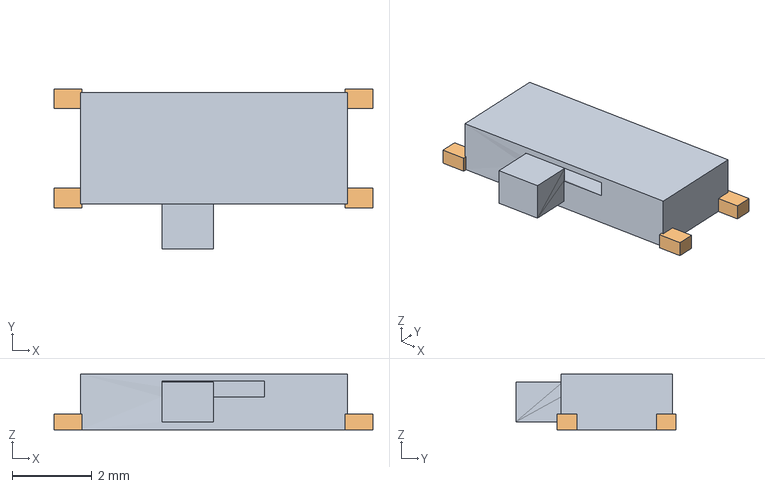
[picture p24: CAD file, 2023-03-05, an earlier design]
Hardware/S3-27-epaper-touch-pro/parts/3d/MK-12C02-G015.step
8.01 x 4.03 x 1.40 mm

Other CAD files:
CaseSTL/Deckelrundeloecher.stl
Hardware/S3-27-epaper-touch-pro/parts/3d/CR1220-2.step
Hardware/S3-27-epaper-touch-pro/parts/3d/IND_0S282MT_SNL.step
Hardware/S3-27-epaper-touch-pro/parts/3d/FH12-24S-0.5SH_55_.step
Hardware/S3-27-epaper-touch-pro/parts/3d/AP22802AW5-7.step

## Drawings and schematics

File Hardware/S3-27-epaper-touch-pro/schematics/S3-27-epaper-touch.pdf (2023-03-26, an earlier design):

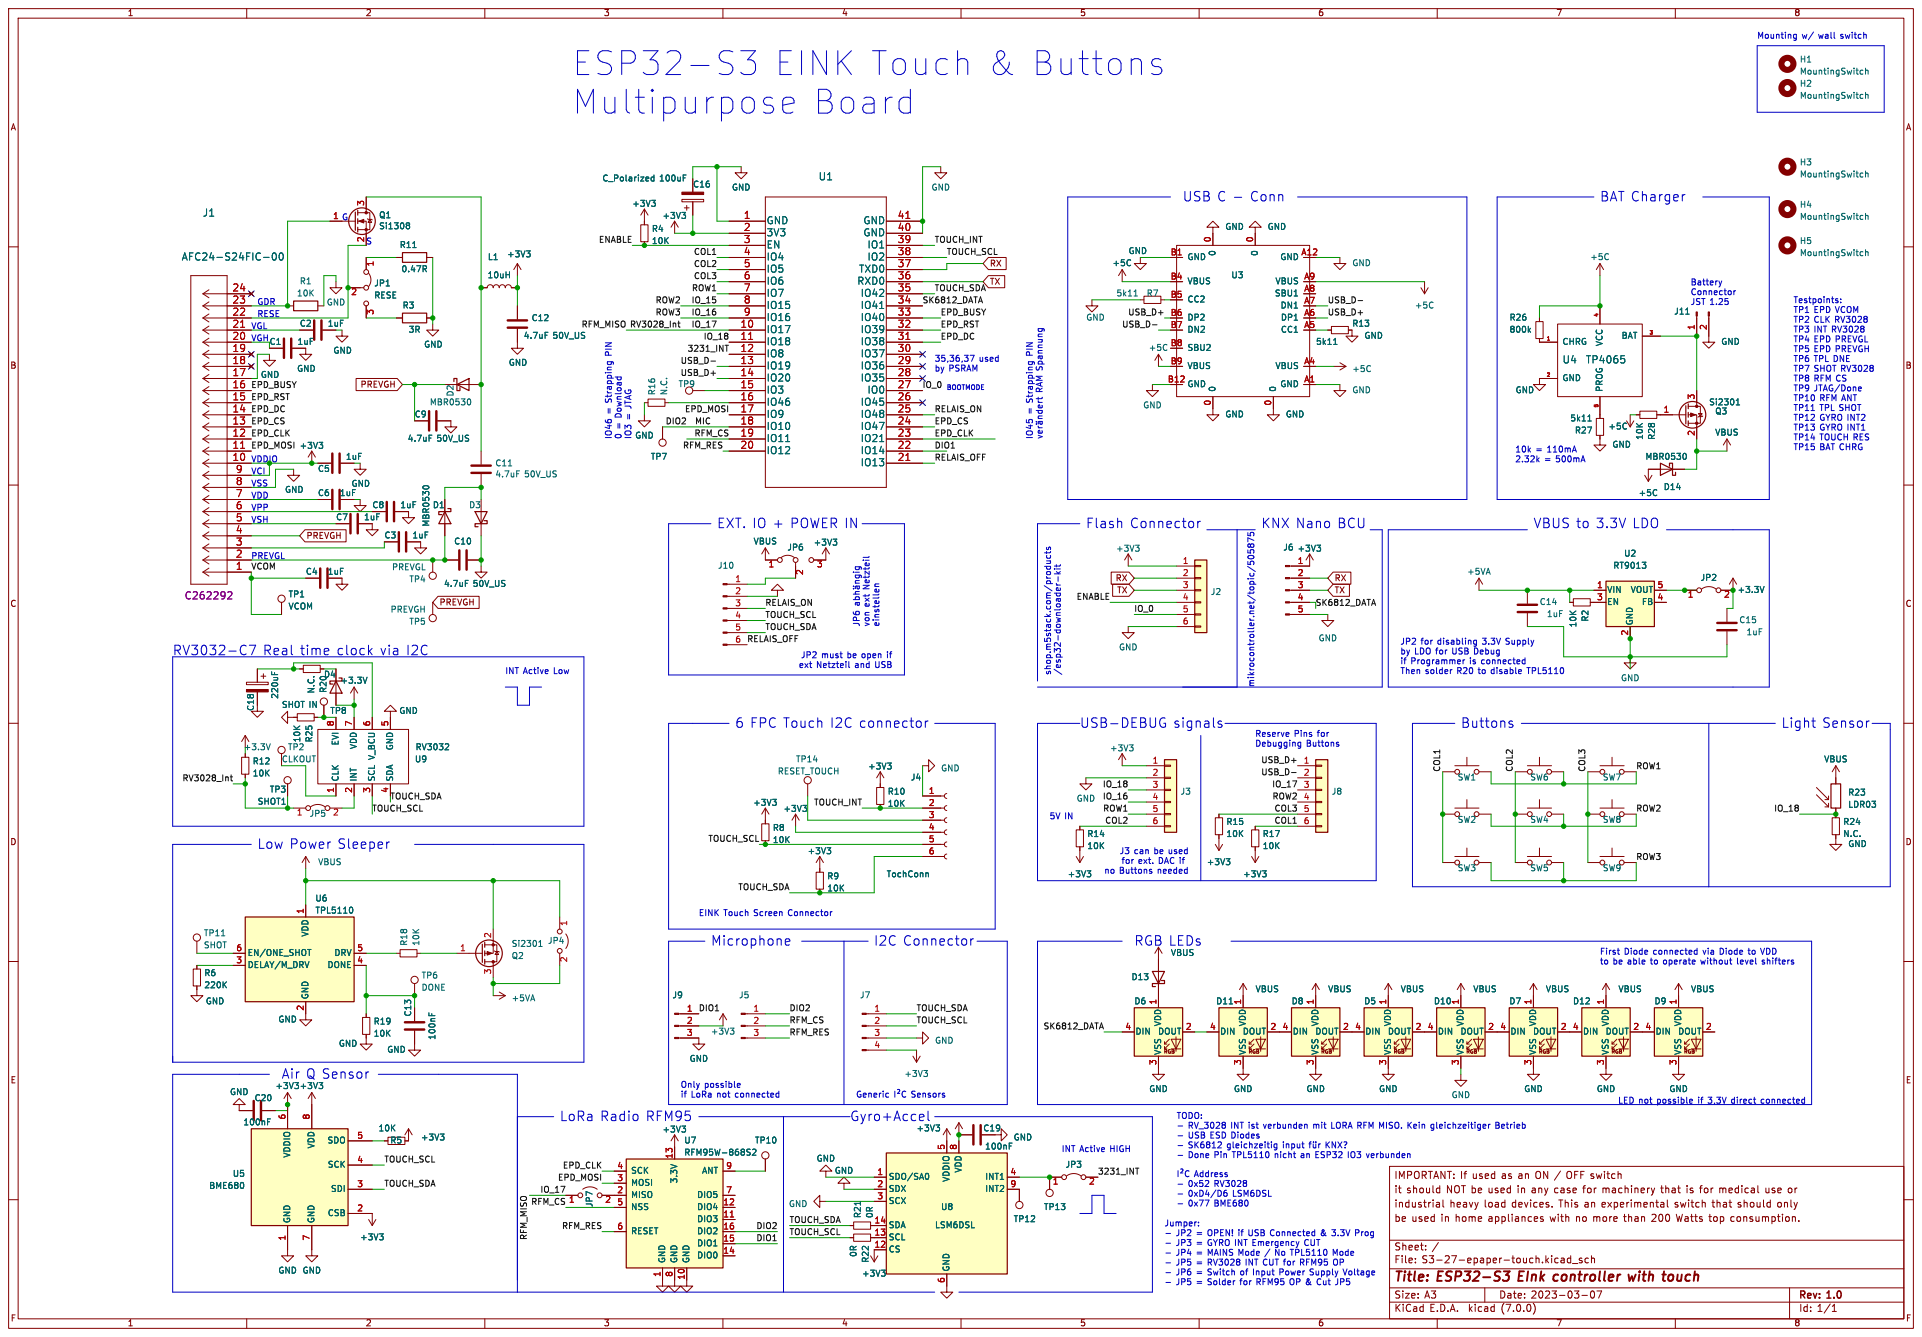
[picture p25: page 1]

Mounting w/ wall switch IO46 = Strapping PIN
TP9C16 C_Polarized 100uF

0 GND A1 GND A12 VBUS A4 CC1 A5 DP1 A6 DN1 A7 SBU1 A8 VBUS A9 GND B1 GND B12 VBUS B4 CC2 B5 DP2 B6 DN2 B7 SBU2 B8 VBUS B9 GND N.C. R20 TP8 SHOT IN

0 GND A1 GND A12 VBUS A4 CC1 A5 DP1 A6 DN1 A7 SBU1 A8 VBUS A9 GND B1 GND B12 VBUS B4 CC2 B5 DP2 B6 DN2 B7 SBU2 B8 VBUS B9 U3 GND GND

TP2 CLK RV3028 TP3 INT RV3028 TP4 EPD PREVGL TP5 EPD PREVGH

7 EVI 8 GND GND GND

TP9 JTAG/Done TP10 RFM ANT

TP11 TPL SHOT
TP12 GYRO INT2 TP13 GYRO INT1 TP14 TOUCH RES

by LDO for USB Debug

JP2 must be open if ext Netzteil and USB

for ext. DAC if no Buttons needed USB-DEBUG signals

2 DELAY/M_DRV 3 DONE 4 DRV 5 EN/ONE_SHOT 6 U6 TPL5110
TP11 SHOT GND

2 DELAY/M_DRV 3 DONE 4 DRV 5 EN/ONE_SHOT 6 R6

First Diode connected via Diode to VDD
to be able to operate without level shifters

3 DIN 4 VBUS VBUS GND GND GND

3 DIN 4 D10 VBUS VBUS GND

3 DIN 4 VBUS VBUS GND

LED not possible if 3,3V direct connected

1 CSB 2 SDI 3 SCK 4 SDO 5 VDDIO

- USB ESD Diodes
- Done Pin TPL5110 nicht an ESP32 IO3 verbunden
þÿI²CAddress

1 GND 10 DIO3 11 DIO4 12 3.3V 13 DIO0 14 DIO1 15 DIO2 16 MISO 2 MOSI 3 SCK 4 NSS 5 RESET 6 DIO5 7 GND

LSM6DSL SDO/SA0 1 CS 12 SCL 13 SDA 14 SDX 2 SCX 3

Jumper: - JP2 = OPEN! if USB Connected & 3.3V Prog

- JP3 = GYRO INT Emergency CUT
- JP4 = MAINS Mode / No TPL5110 Mode
- JP5 = RV3028 INT CUT for RFM95 OP
- JP6 = Switch of Input Power Supply Voltage
- JP5 = Solder for RFM95 OP & Cut JP5

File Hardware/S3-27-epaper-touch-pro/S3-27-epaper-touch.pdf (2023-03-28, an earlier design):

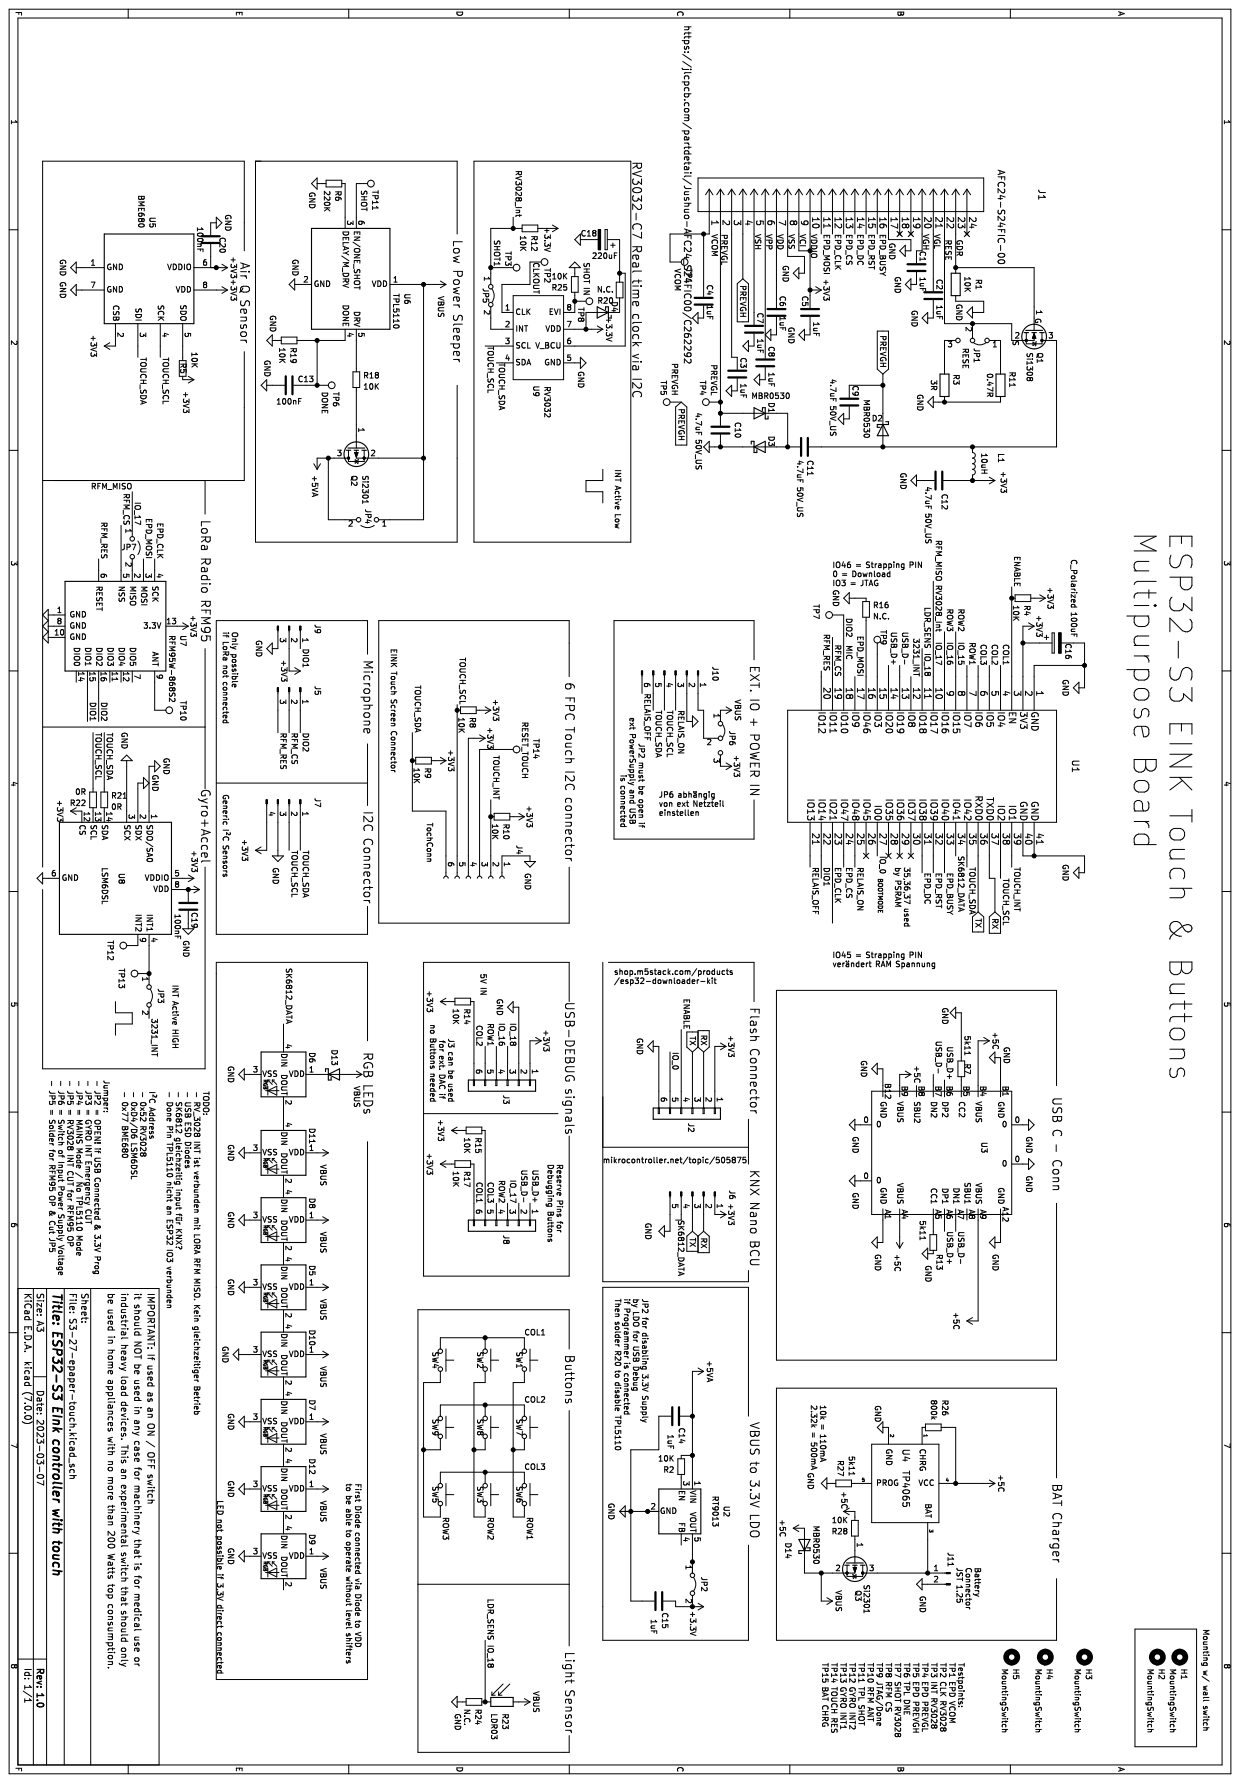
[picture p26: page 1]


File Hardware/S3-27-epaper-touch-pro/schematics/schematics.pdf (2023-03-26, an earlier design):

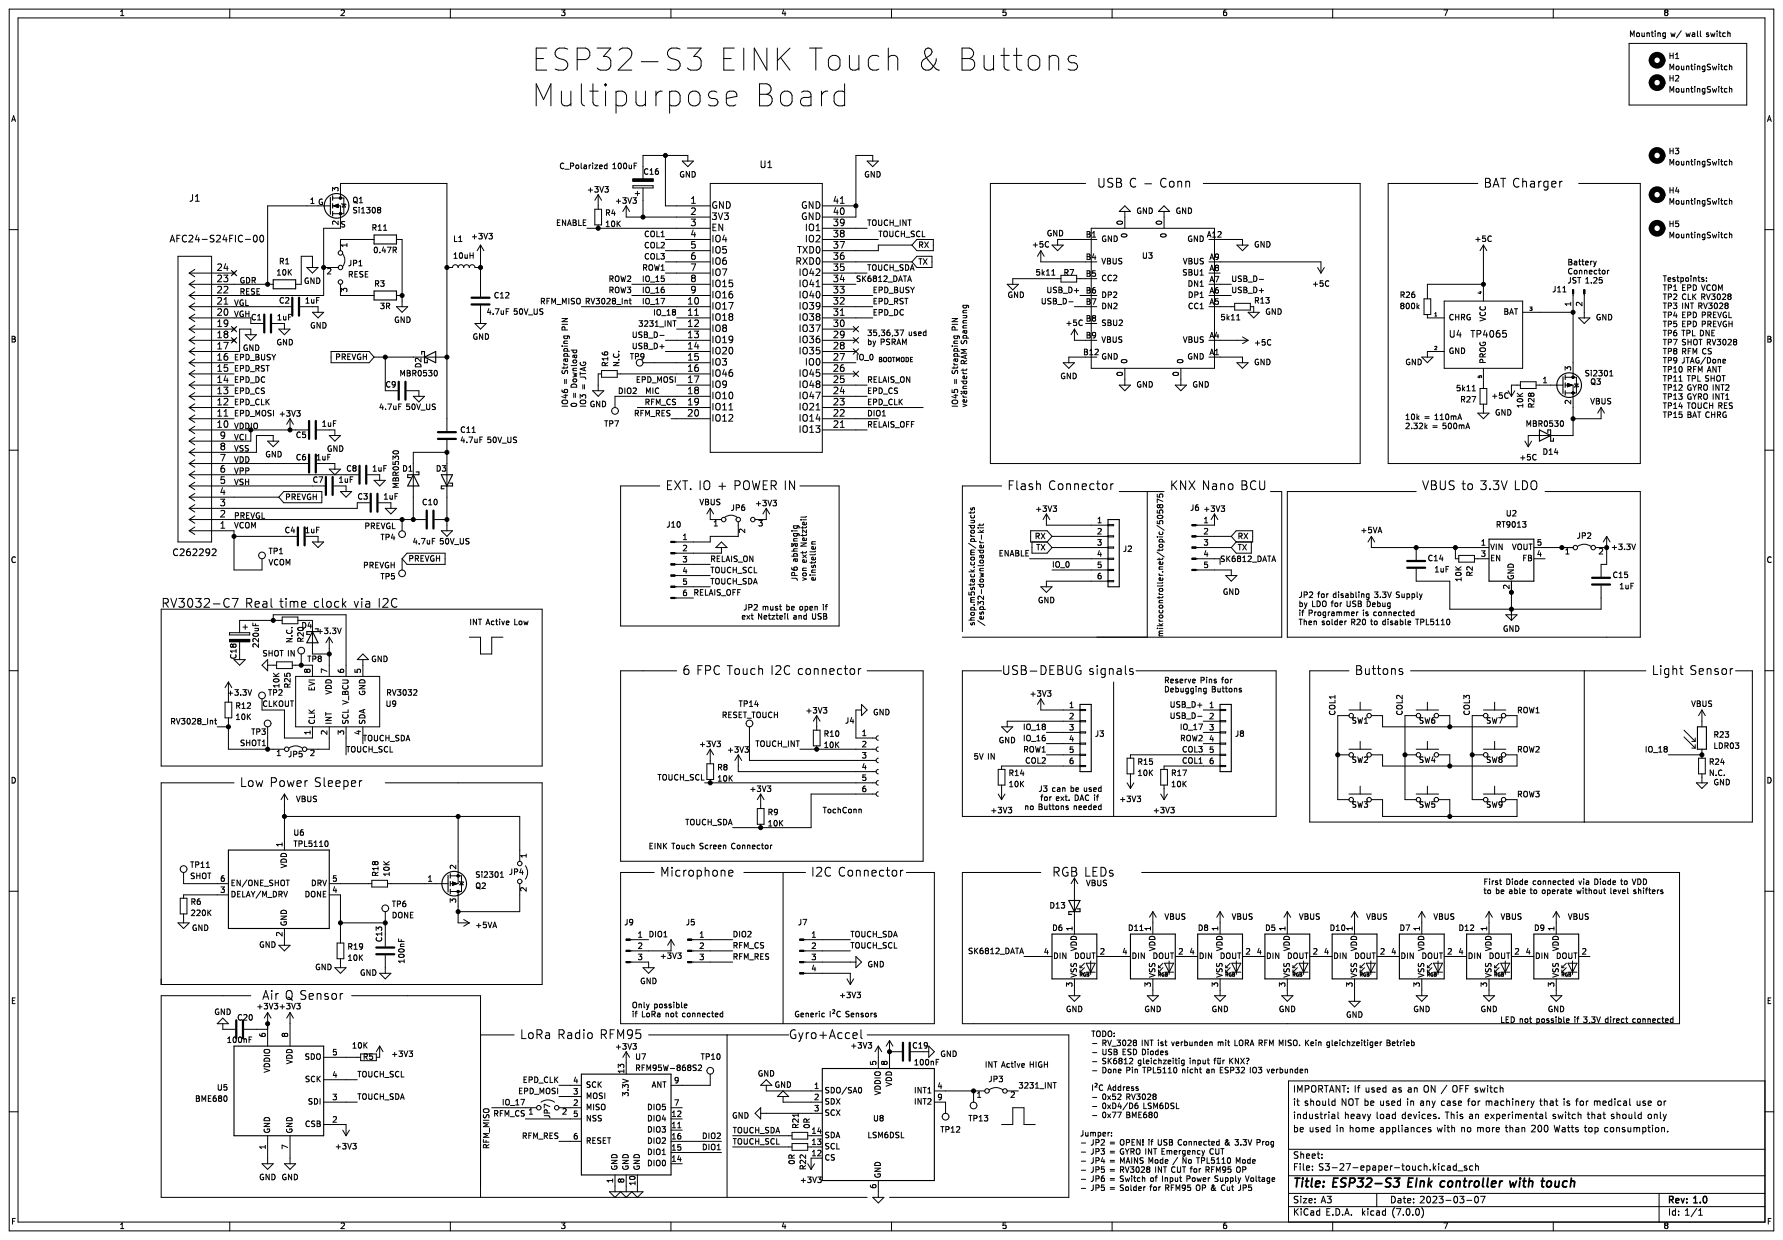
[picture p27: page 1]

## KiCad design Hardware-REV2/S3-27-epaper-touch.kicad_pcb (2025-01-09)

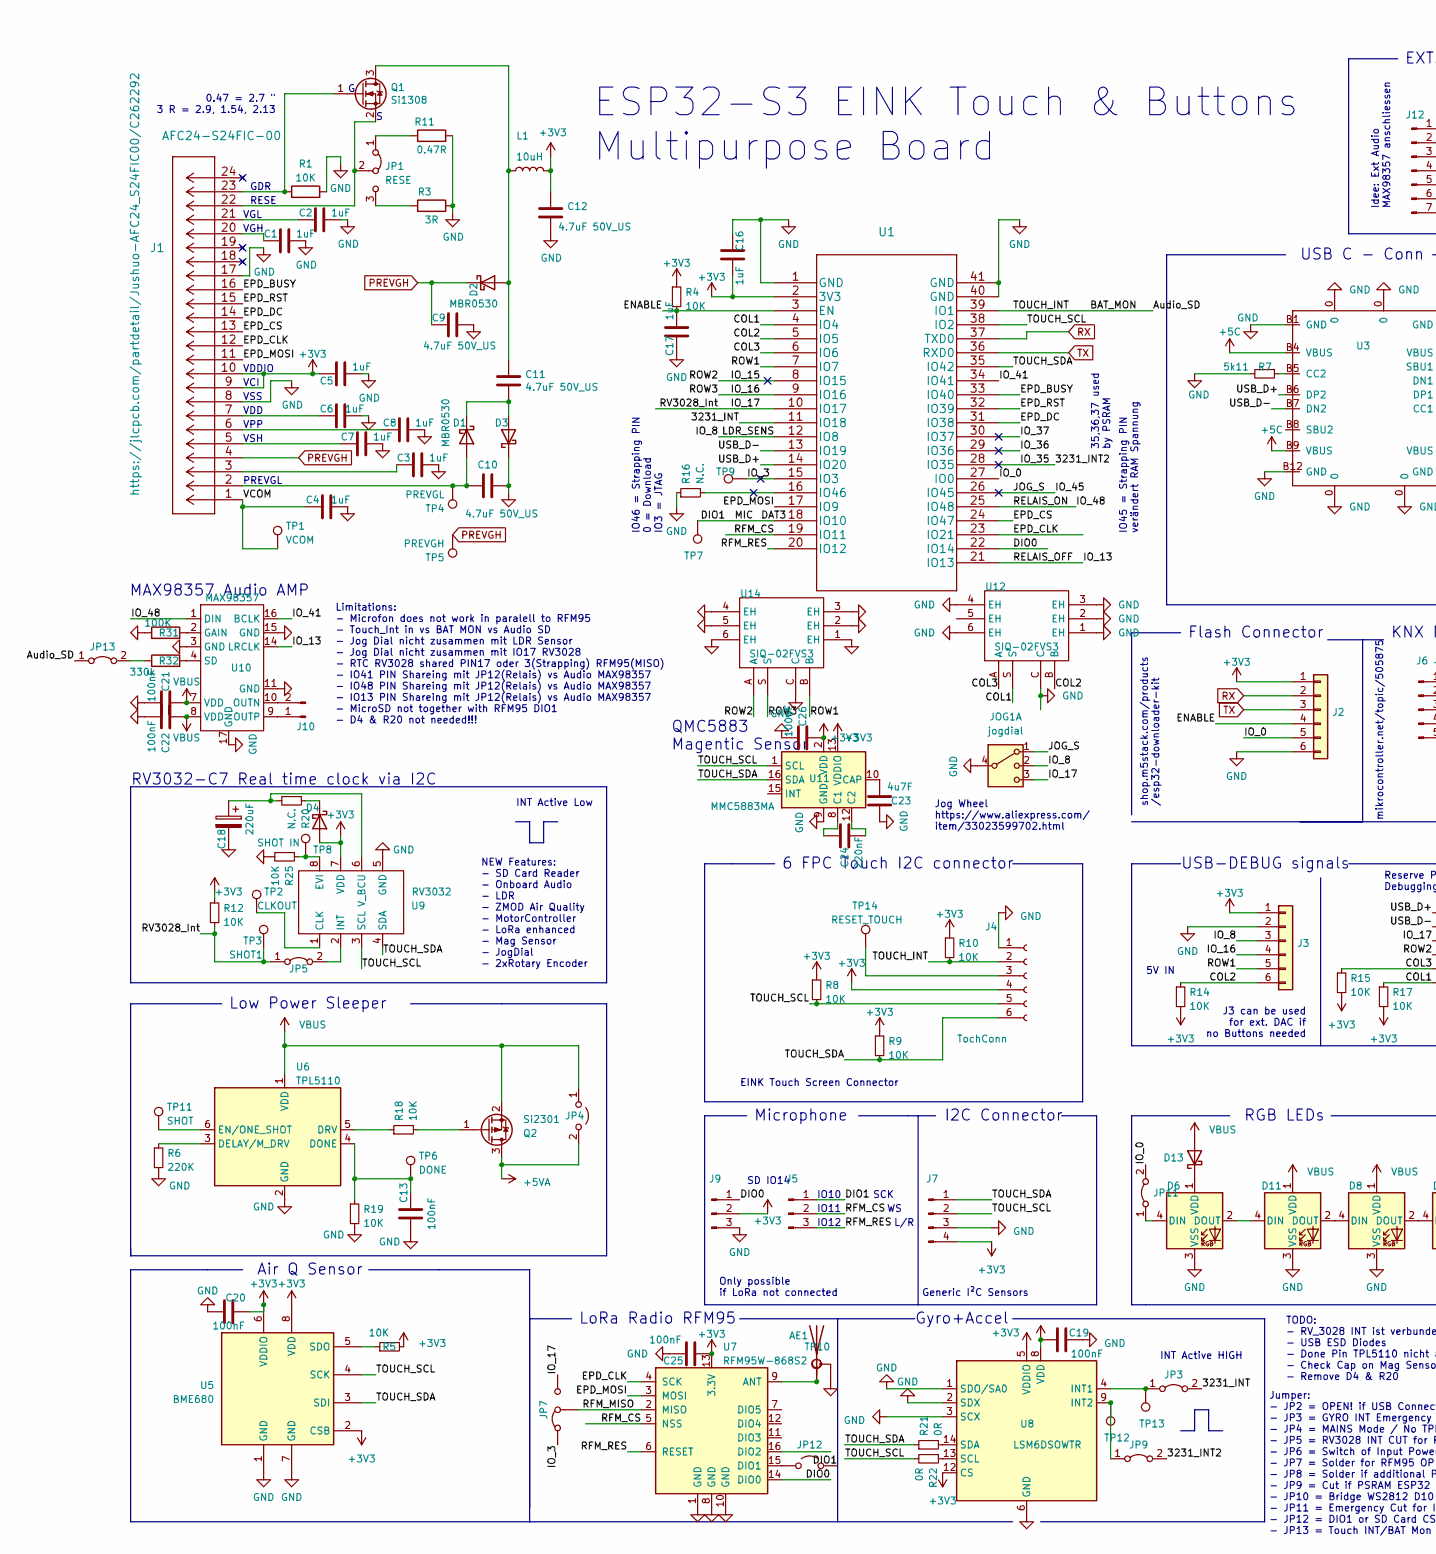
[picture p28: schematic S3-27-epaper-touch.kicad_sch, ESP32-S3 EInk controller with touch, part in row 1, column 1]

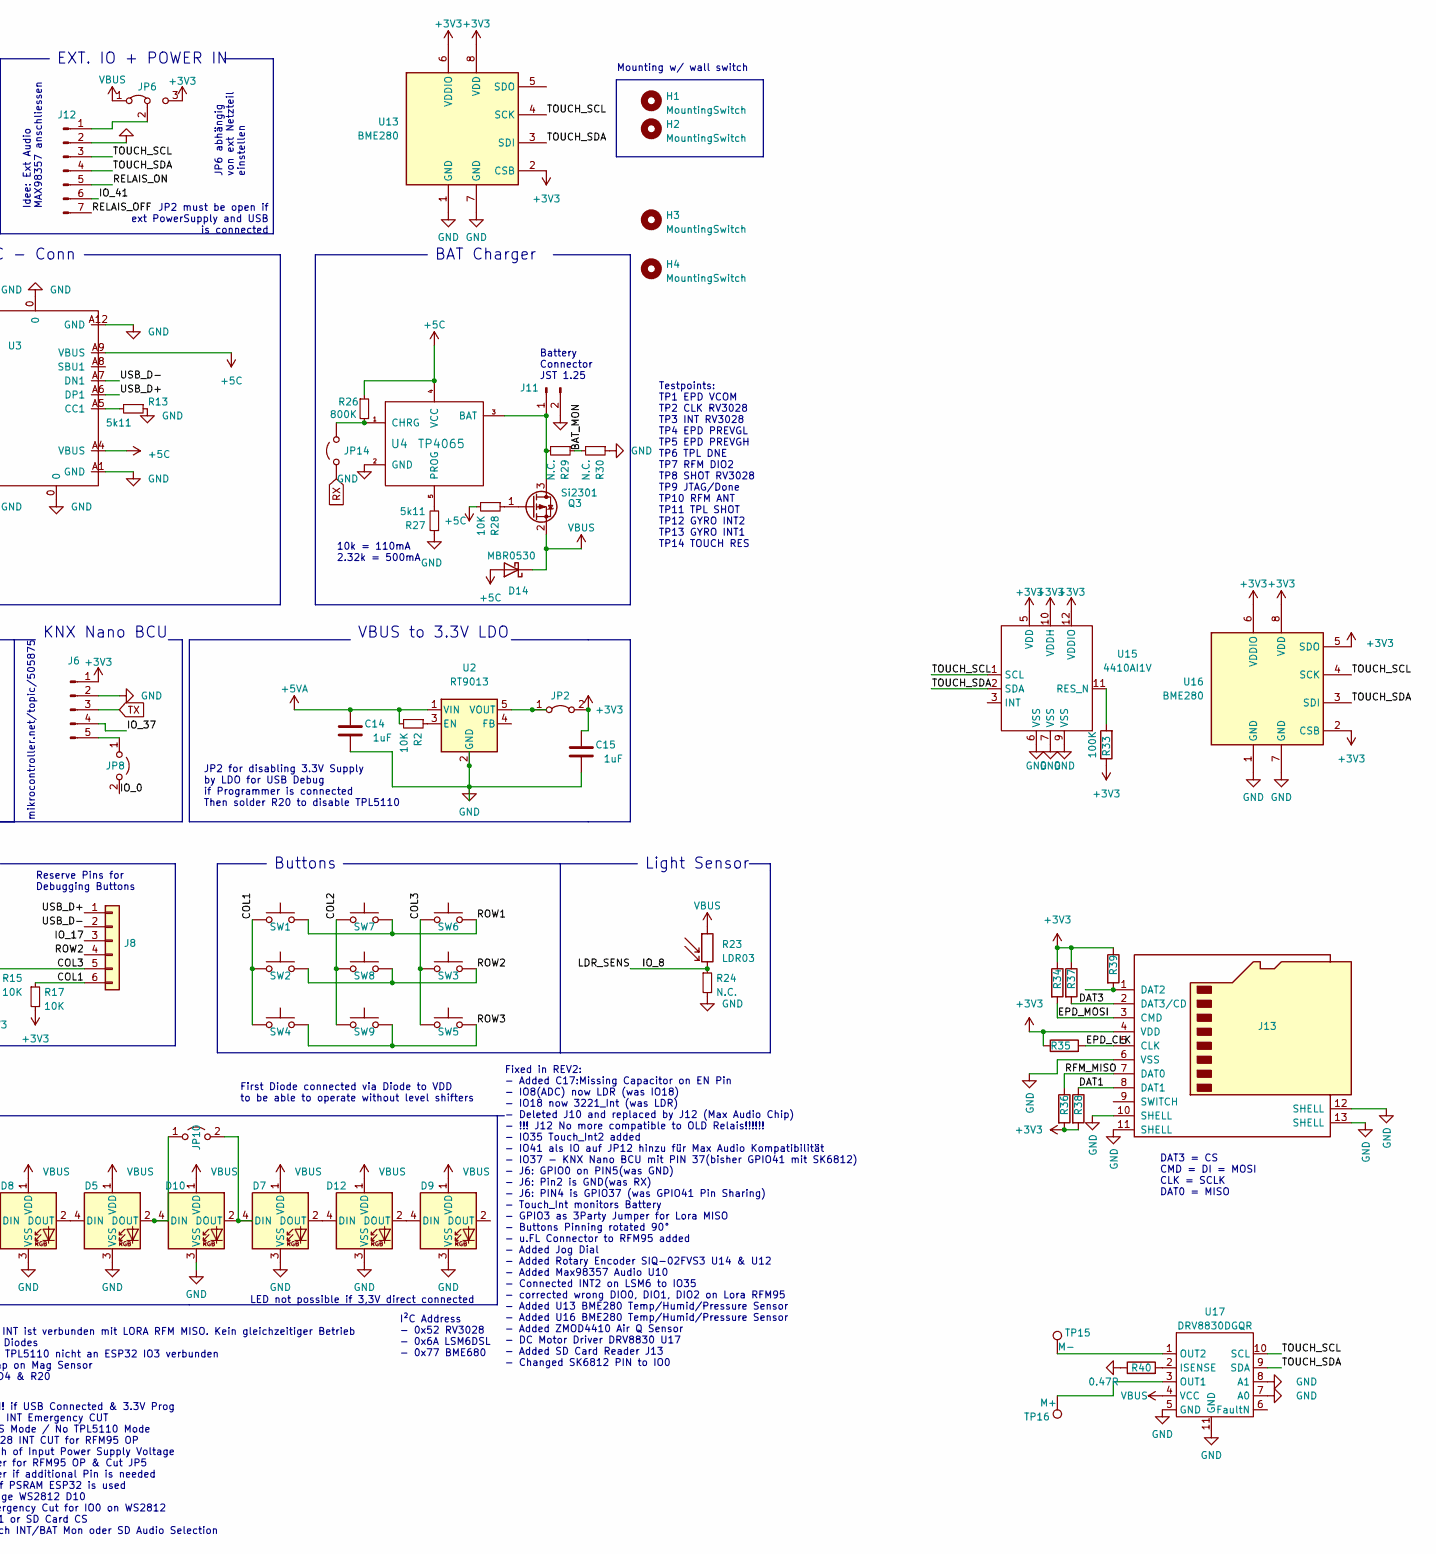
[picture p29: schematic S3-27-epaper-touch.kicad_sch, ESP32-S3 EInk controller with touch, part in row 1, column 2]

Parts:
AE1: Antenna_Shield; U.FL_Molex_MCRF_73412-0110_Vertical
C1, C2, C3, C4, C5, C6, C7, C8, C14, C15, C16, C17: 1uF; C_0805_2012Metric_Pad1.18x1.45mm_HandSolder; LCSC C28323
C9, C10, C11, C12: 4.7uF 50V_US; C_0805_2012Metric_Pad1.18x1.45mm_HandSolder; LCSC C162420
C13, C19, C20: 100nF; C_0805_2012Metric_Pad1.18x1.45mm_HandSolder; LCSC C49678
C18: 220uF; CP_EIA-3528-21_Kemet-B
C21, C22, C26: 100nF; C_0805_2012Metric_Pad1.18x1.45mm_HandSolder
C23: 4u7F; C_0805_2012Metric_Pad1.18x1.45mm_HandSolder
C24: 220nF; C_0805_2012Metric_Pad1.18x1.45mm_HandSolder
C25: 100nF; C_0603_1608Metric_Pad1.08x0.95mm_HandSolder
D1, D2, D3, D4, D13, D14: MBR0530; D_SOD-123
D5, D6, D7, D8, D9, D10, D11, D12: SK6812MINI-E; MX_SK6812MINI-E
H1, H2: MountingSwitch; MountingHole_3.2mm_M3
H3, H4: MountingSwitch; baerklein
J1: AFC24-S24FIC-00; FPC-SMD_P0.50-24P_QCHF-SM-H2.0; LCSC C262292
J2, J3, J8: Conn_01x06; PinHeader_1x06_P2.54mm_Vertical
J4: TochConn; FFC-SMD_6P-P0.50_FH34SRJ-6S-0.5SH; LCSC C224194
J5, J9: Conn_01x03_Pin; PinHeader_1x03_P2.54mm_Vertical
J6: Conn_01x05_Pin; PinHeader_1x05_P2.54mm_Vertical
J7: Conn_01x04_Pin; PinHeader_1x04_P2.54mm_Vertical
J10: Conn_01x02_Pin; PinHeader_1x02_P2.00mm_Vertical
J11: Conn_01x02_Pin; JST_GH_SM02B-GHS-TB_1x02-1MP_P1.25mm_Horizontal
J12: Conn_01x07_Pin; PinHeader_1x07_P2.54mm_Vertical
J13: Micro_SD_Card_Det_US; TF-SMD_XKTF-0803-0
JOG1: jogdial; JogWheel
JP1: RESE; SW-SMD_G-SWITCH_MK-12C02-G015; LCSC C2911519
JP2, JP3, JP5, JP11: Jumper_2_Bridged; SolderJumper-2_P1.3mm_Bridged_RoundedPad1.0x1.5mm
JP4, JP8, JP12, JP14: Jumper_2_Open; SolderJumper-2_P1.3mm_Open_RoundedPad1.0x1.5mm
JP6, JP7: Jumper_3_Bridged12; SolderJumper-3_P1.3mm_Bridged12_RoundedPad1.0x1.5mm_NumberL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
JP9, JP13: Jumper_2_Bridged; SolderJumper-2_P1.3mm_Open_RoundedPad1.0x1.5mm
JP10: Jumper_2_Open; SolderJumper-2_P1.3mm_Bridged_RoundedPad1.0x1.5mm
L1: 10uH; IND-SMD_L4.0-W4.0
Q1: Si1308; SOT-323_SC-70
Q2, Q3: Si2301; SOT-23
R1, R2, R4, R5, R8, R9, R10, R12, R14, R15, R17, R18, R19, R25, R28: 10K; R_0805_2012Metric_Pad1.20x1.40mm_HandSolder; LCSC C17414
R3: 3R; R_0805_2012Metric_Pad1.20x1.40mm_HandSolder
R6: 220K; R_0805_2012Metric_Pad1.20x1.40mm_HandSolder
R7, R13, R27: 5k11; R_0805_2012Metric_Pad1.20x1.40mm_HandSolder; LCSC C27834
R11, R40: 0.47R; R_0805_2012Metric_Pad1.20x1.40mm_HandSolder
R16, R24, R29, R30: N.C.; R_0603_1608Metric_Pad0.98x0.95mm_HandSolder
R20: N.C.; R_0805_2012Metric_Pad1.20x1.40mm_HandSolder
R21, R22: 0R; R_0805_2012Metric_Pad1.20x1.40mm_HandSolder; LCSC C17477
R23: LDR03; R_LDR_10x8.5mm_P7.6mm_Vertical
R26: 800K; R_0805_2012Metric_Pad1.20x1.40mm_HandSolder
R31: 100K; R_0805_2012Metric_Pad1.20x1.40mm_HandSolder
R32: 330k; R_0805_2012Metric_Pad1.20x1.40mm_HandSolder
R33: 100K; R_0603_1608Metric_Pad0.98x0.95mm_HandSolder
R34, R35, R36, R37, R38, R39: 10k; R_0603_1608Metric_Pad0.98x0.95mm_HandSolder
SW1, SW2, SW3, SW4, SW5, SW6, SW7, SW8, SW9: SW_Push; SW-SMD_4P-CORR-L5.2-W5.2-P3.70-LS6.4
TP1, TP7, TP9, TP13: VCOM; TestPoint_Pad_D1.5mm
TP2: CLKOUT; TestPoint_Pad_D1.5mm
TP3: SHOT1; TestPoint_Pad_D1.5mm
TP4: PREVGL; TestPoint_Pad_D1.5mm
TP5: PREVGH; TestPoint_Pad_D1.5mm
TP6: DONE; TestPoint_Pad_D1.5mm
TP8: SHOT IN; TestPoint_Pad_D1.5mm
TP10: VCOM; PinHeader_1x01_P2.54mm_Vertical
TP11: SHOT; TestPoint_Pad_D1.5mm
TP12: VCOM; TestPoint_Pad_D1.0mm
TP14: RESET_TOUCH; TestPoint_Pad_D1.5mm
TP15: M-; TestPoint_Pad_D1.0mm
TP16: M+; TestPoint_Pad_D1.0mm
U1: ESP32-S3-WROOM-1-N8; ESP32-S3-WROOM-1
U2: RT9013; SOT-23-5; LCSC C47773
U3: KoreanHropartsElecTYPE-C-31-M-12; USB-C_SMD-TYPE-C-31-M-12; LCSC C165948
U4: TP4065; SOT-23-5_L3.0-W1.7-P0.95-LS2.8-BR; LCSC C113540
U5: BME680; LGA-8_L3.0-W3.0-P0.80-TR; LCSC C125972
U6: TPL5110; SOT-23-6; LCSC C125830
U7: RFM95W-868S2; HOPERF_RFM9XW_SMD; LCSC C2844472
U8: LSM6DSOWTR; LGA-14_3x2.5mm_P0.5mm_LayoutBorder3x4y; LCSC C2829074
U9: RV3032; rv3028
U10: MAX98357; TQFN-16_L3.0-W3.0-P0.50-BL-EP1.5
U11: MMC5883MA; LGA-16_3x3mm_P0.5mm
U12, U14: SIQ-02FVS3; SW-SMD_SIQ-02FVS3_1; Manufacturer Part SIQ-02FVS3; LCSC Part Name 拨轮滚轮旋转编码器开关
U13, U16: BME280; Bosch_LGA-8_2.5x2.5mm_P0.65mm_ClockwisePinNumbering
U15: 4410AI1V; ZMOD4410AI1V
U17: DRV8830DGQR; HVSSOP-10-1EP_3x3mm_P0.5mm_EP1.57x1.88mm

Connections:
+3V3: C5.2, C12.2, C15.1, C16.1, C19.2, C20.2, C25.2, C26.1, D4.2 (A), J1.9, J1.10, J2.1, J3.1, J4.4, J6.1, J7.4, J9.2, J13.4 (VDD), JP2.2 (B), JP6.3 (B), L1.2, R4.1, R5.2, R8.1, R9.1, R10.1, R12.1, R14.2, R15.2, R17.2, R33.1, R34.1, R35.1, R36.2, R37.1, R38.2, R39.1, U1.2 (3V3), U5.2 (CSB), U5.6 (VDDIO), U5.8 (VDD), U7.13 (3.3V), U8.5 (VDDIO), U8.8 (VDD), U8.12 (CS), U9.7 (VDD), U11.2 (VDD), U11.13 (VDDIO), U13.2 (CSB), U13.6 (VDDIO), U13.8 (VDD), U15.5 (VDD), U15.10 (VDDH), U15.12 (VDDIO), U16.2 (CSB), U16.5 (SDO), U16.6 (VDDIO), U16.8 (VDD)
+5C: D14.2 (A), R26.1, R28.2, U3.A4 (VBUS), U3.A9 (VBUS), U3.B4 (VBUS), U3.B9 (VBUS), U4.4 (VCC)
+5VA: C14.1, JP4.2 (B), Q2.3 (D), R2.2, U2.1 (VIN)
/3231_INT: JP3.2 (B), U1.11 (IO18)
/3231_INT2: JP9.2 (B), U1.28 (IO35)
/Audio_SD: J4.2, JP13.1 (A), R10.2, R29.1, R30.2, U1.39 (IO1)
/COL1: J8.6, R17.1, SW1.1, SW2.1, SW4.1, U1.4 (IO4), U12.S
/COL2: J3.6, R14.1, SW7.1, SW8.1, SW9.1, U1.5 (IO5), U12.B
/COL3: J8.5, R15.1, SW3.1, SW5.1, SW6.1, U1.6 (IO6), U12.A
/DAT1: J13.8 (DAT1), R38.1
/DAT3: J5.1, J13.2 (DAT3/CD), JP12.2 (B), R37.2, TP7.1, U1.18 (IO10)
/DIO0: J9.1, U1.22 (IO14), U7.14 (DIO0)
/ENABLE: C17.1, J2.4, R4.2, U1.3 (EN)
/EPD_BUSY: J1.16, U1.33 (IO40)
/EPD_CLK: J1.12, J13.5 (CLK), R35.2, U1.23 (IO21), U7.4 (SCK)
/EPD_CS: J1.13, U1.24 (IO47)
/EPD_DC: J1.14, U1.31 (IO38)
/EPD_MOSI: J1.11, J13.3 (CMD), R34.2, U1.17 (IO9), U7.3 (MOSI)
/EPD_RST: J1.15, U1.32 (IO39)
/IO_0: J2.5, JP8.2 (B), JP11.2 (B), U1.27 (IO0)
/IO_3: JP7.1 (A), TP9.1, U1.15 (IO3)
/IO_8: J3.3, JOG1.2, R23.2, R24.1, U1.12 (IO8); also elsewhere on the board
/IO_13: J12.7, U1.21 (IO13), U10.14 (LRCLK)
/IO_15: J8.4, SW2.2, SW3.2, SW8.2, U1.8 (IO15), U14.A
/IO_16: J3.4, SW4.2, SW5.2, SW9.2, U1.9 (IO16), U14.S
/IO_17: J8.3, JOG1.3, JP5.1 (A), JP7.3 (B), R12.2, TP3.1, U1.10 (IO17); also elsewhere on the board
/IO_36: U1.29 (IO36)
/IO_37: J6.4, U1.30 (IO37)
/IO_41: J12.6, U1.34 (IO41), U10.16 (BCLK)
/IO_45: JOG1.1, U1.26 (IO45); also elsewhere on the board
/IO_48: J12.5, U1.25 (IO48), U10.1 (DIN)
/RFM_CS: J5.2, U1.19 (IO11), U7.5 (NSS)
/RFM_MISO: J13.7 (DAT0), JP7.2 (C), R36.1, U7.2 (MISO)
/RFM_RES: J5.3, U1.20 (IO12), U7.6 (RESET)
/ROW1: J3.5, SW1.2, SW6.2, SW7.2, U1.7 (IO7), U14.B
/TOUCH_SCL: J4.5, J7.2, J12.3, R8.2, R22.2, U1.38 (IO2), U5.4 (SCK), U9.3 (SCL), U11.1 (SCL), U13.4 (SCK), U15.1 (SCL), U16.4 (SCK), U17.10 (SCL)
/TOUCH_SDA: J4.6, J7.1, J12.4, R9.2, R21.1, U1.35 (IO42), U5.3 (SDI), U9.4 (SDA), U11.16 (SDA), U13.3 (SDI), U15.2 (SDA), U16.3 (SDI), U17.9 (SDA)
/USB_D+: J8.1, U1.14 (IO20), U3.A6 (DP1), U3.B6 (DP2)
/USB_D-: J8.2, U1.13 (IO19), U3.A7 (DN1), U3.B7 (DN2)
/VCOM: C4.2, J1.1, TP1.1
GND: AE1.2 (Shield), C1.1, C2.1, C3.1, C4.1, C5.1, C6.1, C7.1, C8.1, C9.1, C10.1, C12.1, C13.2, C14.2, C15.2, C16.2, C17.2, C18.2, C19.1, C20.1, C21.2, C22.2, C23.1, C25.1, C26.2, D3.1 (K), D5.3 (VSS), D6.3 (VSS), D7.3 (VSS), D8.3 (VSS), D9.3 (VSS), D10.3 (VSS), D11.3 (VSS), D12.3 (VSS), J1.8, J1.17, J2.6, J3.2, J4.1, J6.2, J7.3, J9.3, J11.2, J12.2, J13.6 (VSS), J13.10 (SHELL), J13.11 (SHELL), J13.12 (SHELL), J13.13 (SHELL), JOG1.4, R1.2, R3.2, R6.2, R7.2, R11.2, R13.1, R16.1, R19.2, R24.2, R25.2, R27.1, R30.1, R31.1, R40.1, U1.1 (GND), U1.40 (GND), U1.41 (GND), U2.2 (GND), U3.0, U3.A1 (GND), U3.A12 (GND), U3.B1 (GND), U3.B12 (GND), U4.2 (GND), U5.1 (GND), U5.7 (GND), U6.2 (GND), U7.1 (GND), U7.8 (GND), U7.10 (GND), U8.1 (SDO/SA0), U8.2 (SDX), U8.3 (SCX), U8.6 (GND), U8.7 (GND), U9.5 (GND), U10.3 (GND), U10.11 (GND), U10.15 (GND), U10.17 (GND), U11.9 (GND), U11.11 (GND), U12.1 (EH), U12.2 (EH), U12.3 (EH), U12.4 (EH), U12.6 (EH), U12.C, U13.1 (GND), U13.7 (GND), U14.1 (EH), U14.2 (EH), U14.3 (EH), U14.4 (EH), U14.5 (EH), U14.6 (EH), U14.C, U15.6 (VSS), U15.7 (VSS), U15.9 (VSS), U16.1 (GND), U16.7 (GND), U17.5 (GND), U17.7 (A0), U17.8 (A1), U17.11 (GND); also elsewhere on the board
unnamed: AE1.1 (A), TP10.1, U7.9 (ANT)
unnamed: C1.2, J1.20
unnamed: C2.2, J1.21
unnamed: C3.2, J1.3
unnamed: C6.2, J1.7
unnamed: C7.2, J1.5
unnamed: C8.2, J1.6
unnamed: C10.2, D1.2 (A), J1.2, TP4.1
unnamed: C11.1, D1.1 (K), D3.2 (A)
unnamed: C11.2, D2.2 (A), L1.1, Q1.3 (D)
unnamed: D4.1 (K), R20.1
unnamed: D5.4 (DIN), D8.2 (DOUT)
unnamed: D6.4 (DIN), JP11.1 (A)
unnamed: D5.2 (DOUT), D10.4 (DIN), JP10.1 (A)
unnamed: D7.4 (DIN), D10.2 (DOUT), JP10.2 (B)
unnamed: D6.2 (DOUT), D11.4 (DIN)
unnamed: D8.4 (DIN), D11.2 (DOUT)
unnamed: D7.2 (DOUT), D12.4 (DIN)
unnamed: D9.4 (DIN), D12.2 (DOUT)
unnamed: D6.1 (VDD), D13.1 (K)
unnamed: J4.3, TP14.1
unnamed: J6.5, JP8.1 (A)
unnamed: J10.1, U10.9 (OUTP)
unnamed: J10.2, U10.10 (OUTN)
unnamed: J11.1, Q3.3 (D), R29.2, U4.3 (BAT)
unnamed: J12.1, JP6.2 (C)
unnamed: J13.1 (DAT2), R39.2
unnamed: JP1.1 (A), R11.1
unnamed: JP1.3 (B), R3.1
unnamed: J1.22, JP1.2 (C), Q1.2 (S)
unnamed: JP2.1 (A), U2.5 (VOUT)
unnamed: JP3.1 (A), TP13.1, U8.4 (INT1)
unnamed: JP5.2 (B), U9.2 (INT)
unnamed: JP9.1 (A), TP12.1, U8.9 (INT2)
unnamed: JP12.1 (A), U7.15 (DIO1)
unnamed: JP13.2 (B), R32.1
unnamed: JP14.2 (B), R26.2, U4.1 (CHRG)
unnamed: J1.23, Q1.1 (G), R1.1
unnamed: Q2.1 (G), R18.2
unnamed: Q3.1 (G), R28.1
unnamed: R16.2, U1.16 (IO46)
unnamed: R2.1, U2.3 (EN)
unnamed: R13.2, U3.A5 (CC1)
unnamed: R7.1, U3.B5 (CC2)
unnamed: R27.2, U4.5 (PROG)
unnamed: R5.1, U5.5 (SDO)
unnamed: R6.1, U6.3 (DELAY/M_DRV)
unnamed: C13.1, R19.1, TP6.1, U6.4 (DONE)
unnamed: R18.1, U6.5 (DRV)
unnamed: TP11.1, U6.6 (EN/ONE_SHOT)
unnamed: R22.1, U8.13 (SCL)
unnamed: R21.2, U8.14 (SDA)
unnamed: TP2.1, U9.1 (CLK)
unnamed: R25.1, TP8.1, U9.8 (EVI)
unnamed: C18.1, R20.2, U9.6 (V_BCU)
unnamed: R31.2, U10.2 (GAIN)
unnamed: R32.2, U10.4 (SD)
unnamed: C24.1, U11.8 (C1)
unnamed: C24.2, U11.12 (C2)
unnamed: C23.2, U11.10 (CAP)
unnamed: R33.2, U15.11 (RES_N)
unnamed: R40.2, U17.2 (ISENSE)
unnamed: TP16.1, U17.3 (OUT1)
unnamed: TP15.1, U17.1 (OUT2)
PREVGH: C9.2, D2.1 (K), J1.4, TP5.1
RX: J2.2, JP14.1 (A), U1.37 (TXD0)
TX: J2.3, J6.3, U1.36 (RXD0)
VBUS: C21.1, C22.1, D5.1 (VDD), D7.1 (VDD), D8.1 (VDD), D9.1 (VDD), D10.1 (VDD), D11.1 (VDD), D12.1 (VDD), D13.2 (A), D14.1 (K), JP4.1 (A), JP6.1 (A), Q2.2 (S), Q3.2 (S), R23.1, U6.1 (VDD), U10.7 (VDD), U10.8 (VDD), U17.4 (VCC)

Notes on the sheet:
PREVGL
Gyro+Accel
Limitations: - Microfon does not work in paralell to RFM95 - Touch_Int in vs BAT MON vs Audio SD - Jog Dial nicht zusammen mit LDR Sensor - Jog Dial nicht zusammen mit IO17 RV3028 - RTC RV3028 shared PIN17 oder 3(Strapping) RFM95(MISO) - IO41 PIN Shareing mit JP12(Relais) vs Audio MAX98357 - IO48 P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
EXT. IO + POWER IN
RESE
VCI
Testpoints: TP1 EPD VCOM TP2 CLK RV3028 TP3 INT RV3028 TP4 EPD PREVGL TP5 EPD PREVGH TP6 TPL DNE TP7 RFM DIO2 TP8 SHOT RV3028 TP9 JTAG/Done TP10 RFM ANT TP11 TPL SHOT TP12 GYRO INT2 TP13 GYRO INT1 TP14 TOUCH RES
VDDIO
shop.m5stack.com/products /esp32-downloader-kit
IO11
SD IO14
USB-DEBUG signals
JP2 for disabling 3.3V Supply by LDO for USB Debug if Programmer is connected Then solder R20 to disable TPL5110
Microphone
QMC5883 Magentic Sensor
Low Power Sleeper
LED not possible if 3,3V direct connected
MAX98357 Audio AMP
0.47 = 2.7 " 3 R = 2.9, 1.54, 2.13
DAT3 = CS CMD = DI = MOSI CLK = SCLK DAT0 = MISO
RV3032-C7 Real time clock via I2C
35,36,37 used by PSRAM
INT Active Low
5V IN
6 FPC Touch I2C connector
VDD
VSH
Generic I²C Sensors
I²C Address - 0x52 RV3028 - 0x6A LSM6DSL - 0x77 BME680
KNX Nano BCU
TODO: - RV_3028 INT ist verbunden mit LORA RFM MISO. Kein gleichzeitiger Betrieb - USB ESD Diodes - Done Pin TPL5110 nicht an ESP32 IO3 verbunden - Check Cap on Mag Sensor - Remove D4 & R20
VSS
Idee: Ext Audio MAX98357 anschliessen
INT Active HIGH
VPP
JP6 abhängig von ext Netzteil einstellen
SCK
Air Q Sensor
EINK Touch Screen Connector
VGL

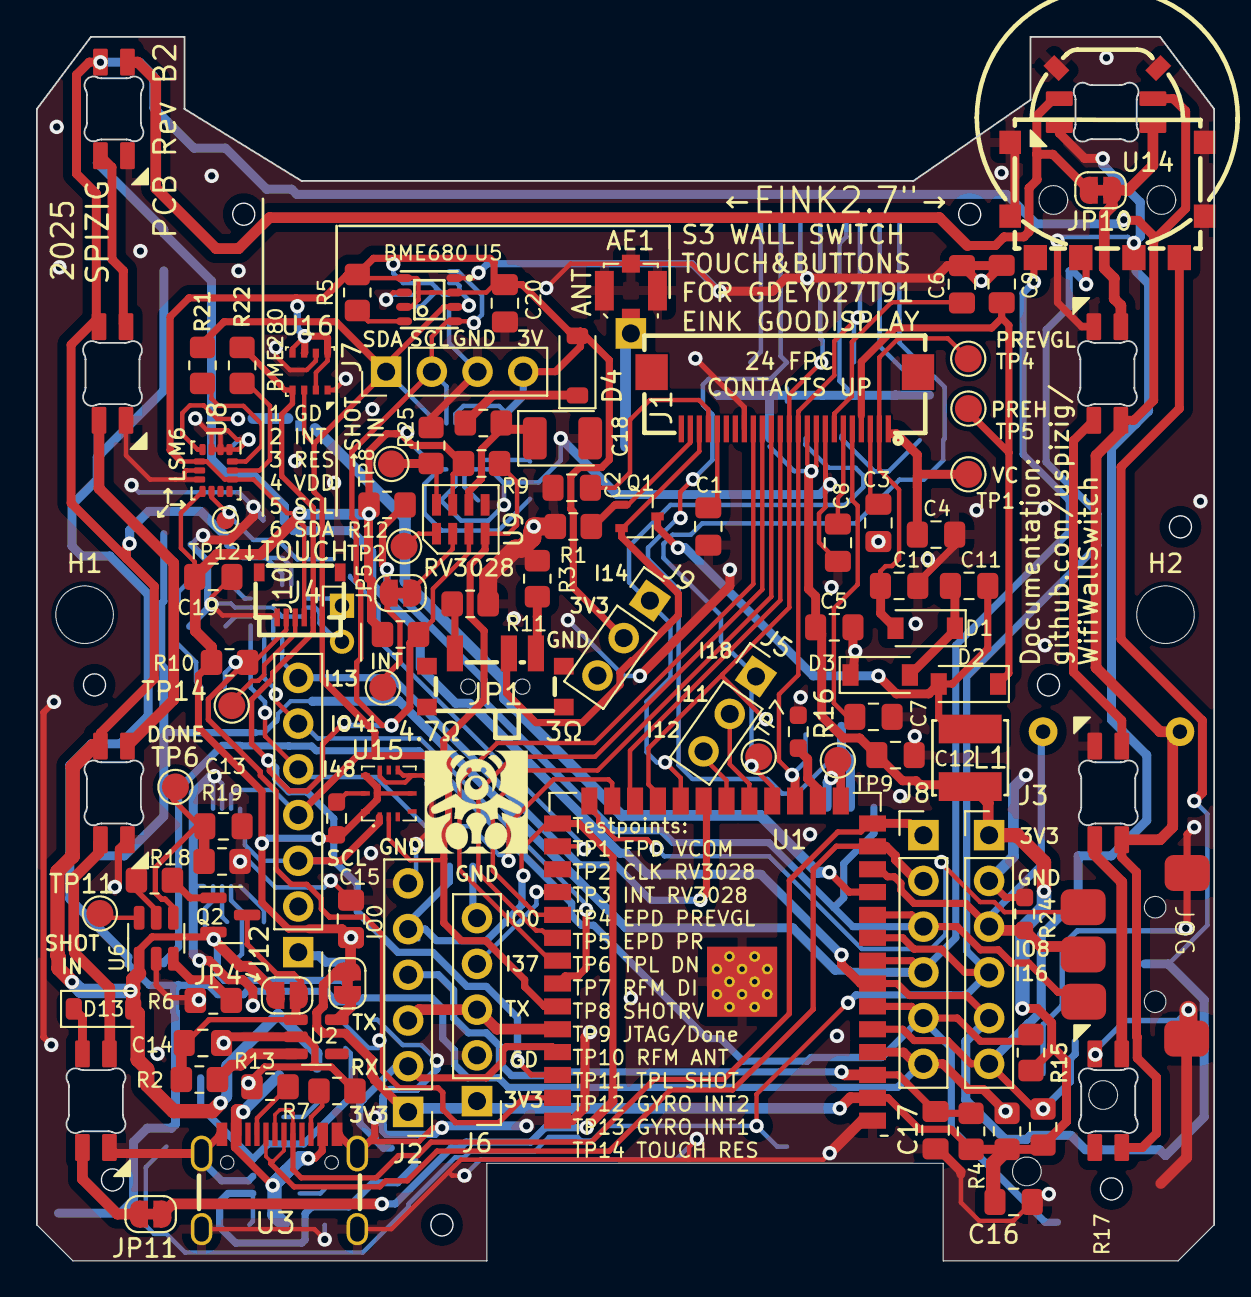
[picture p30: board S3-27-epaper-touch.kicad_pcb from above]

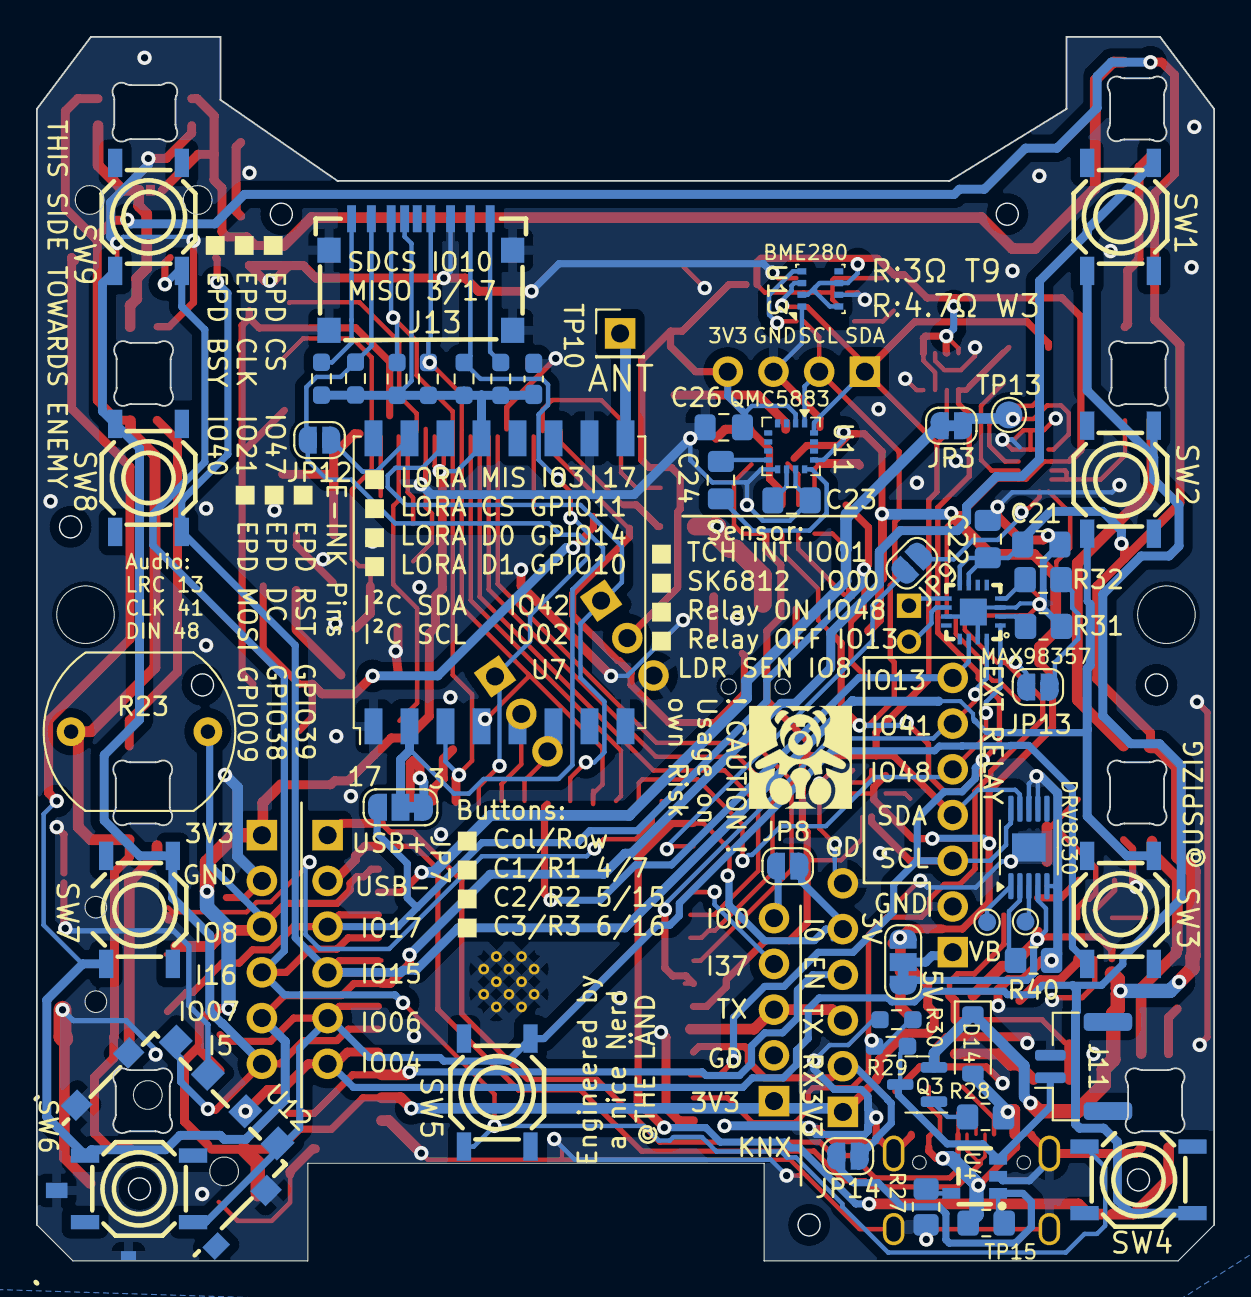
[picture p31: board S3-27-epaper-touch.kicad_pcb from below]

Board: 2 copper layers, 65.4 x 68.0 mm, 159 parts (62 on the bottom side), 108 nets.

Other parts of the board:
JOG: jogdial; JogWheel

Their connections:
/IO_8: JOG.2; also elsewhere on the board
/IO_17: JOG.3; also elsewhere on the board
/IO_45: JOG.1; also elsewhere on the board
GND: JOG.4; also elsewhere on the board

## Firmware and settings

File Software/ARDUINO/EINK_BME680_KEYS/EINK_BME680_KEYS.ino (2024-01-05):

//Display Tap Erkennung
//Anzeige von Werten
//Grafen
// Probleme: immer 500 ppm Co2

//BrownOut Disable
#include "soc/soc.h"
#include "soc/rtc_cntl_reg.h"
//Task Watchdog
#include <esp_task_wdt.h>

//#include <GxEPD.h>//nur für fonts???
#include "user_kennung.h"
#include <time.h>               // In-built

// select the display class to use, only one

//#include <GxGDEW027W3/GxGDEW027W3.h>      // 2.7" b/w
#include <GxEPD2_BW.h>
#include <GxEPD2_3C.h>
#include "GxEPD2_boards_added.h"

// FreeFonts from Adafruit_GFX
#include <Fonts/FreeMonoBold9pt7b.h>
#include <Fonts/FreeMonoBold12pt7b.h>
#include <Fonts/FreeMonoBold18pt7b.h>
#include <Fonts/FreeMono9pt7b.h>
//#include <Fonts/Homemade_Apple_Regular_9.h>
//#include <Fonts/Crafty_Girls_Regular_12.h>
//#include <Fonts/Aclonica_Regular_16.h>
//#include <Fonts/Dialog6pt.h>

//#include <Fonts/FreeSansBold12pt7b.h>
//#include <Fonts/FreeSerifBold12pt7b.h>

const GFXfont* Schrift1 = &FreeMonoBold12pt7b;
const GFXfont* Schrift2 = &FreeMonoBold9pt7b;
const GFXfont* Schrift3 = &FreeMonoBold18pt7b; 
const GFXfont* Schrift4 = &FreeMono9pt7b; 
//const GFXfont* Schrift2 = &Crafty_Girls_Regular_12; 
//const GFXfont* Schrift2 = &Aclonica_Regular_16;
//const GFXfont* Schrift5 = &FreeSansBold12pt7b; 
//const GFXfont* Schrift6 = &Dialog_plain_8;
const GFXfont* Schrift6 = &FreeMono9pt7b; 

#include "SparkFunLSM6DS3.h"
#include "Wire.h"
//https://www.st.com/resource/en/application_note/an5040-lsm6dsl-alwayson-3d-accelerometer-and-3d-gyroscope-stmicroelectronics.pdf

LSM6DS3 myIMU( I2C_MODE, 0x6A );
#define INT1_PIN 8
uint8_t int1Status;



//Messdaten
//RealTimeVariables which don't get erased during Sleep
  struct Daten_struct {//https://esp32.com/viewtopic.php?t=11984
    //uint16_t Stack[15];
    float Stack[15];
    uint8_t Counter_History;
  };
  int IconSize = 11;//10
  int x = 10;
  int y = 40;
  RTC_DATA_ATTR  struct Daten_struct Druck_Werte;                 
  RTC_DATA_ATTR  struct Daten_struct Temp_Werte;
  RTC_DATA_ATTR  struct Daten_struct Feuchte_Werte;

  RTC_DATA_ATTR  struct Daten_struct CO2_Werte;
  RTC_DATA_ATTR  struct Daten_struct TVOC_Werte;                                                   
  RTC_DATA_ATTR  struct Daten_struct IAQ_Werte;                                                   
  RTC_DATA_ATTR  struct Daten_struct STATIC_IAQ_Werte;                                                   

  RTC_DATA_ATTR  struct Daten_struct BREATHEVOC_Werte;
  RTC_DATA_ATTR  struct Daten_struct GAS_Werte;  
  RTC_DATA_ATTR  struct Daten_struct STABILITY_Werte; 
  RTC_DATA_ATTR  struct Daten_struct RUNIN_Werte;
  RTC_DATA_ATTR  struct Daten_struct RUNIN_IAQ_Werte;
  
  RTC_DATA_ATTR  struct Daten_struct ROLL_Werte;
  RTC_DATA_ATTR  struct Daten_struct PITCH_Werte;

    
 


//Uhrzeit:
const char* Timezone    = "CET-1CEST,M3.5.0,M10.5.0/3";  
const char* ntpServer   = "1.de.pool.ntp.org";
int   gmtOffset_sec     = 0;
int   daylightOffset_sec = 3600;
String  Time_str = "--:--:--";
String  Date_str = "-- --- ----";
int     wifi_signal, CurrentHour = 0, CurrentMin = 0, CurrentSec = 0, EventCnt = 0, vref = 1100;
//Day of the week
const char* weekday_D[] = { "So", "Mo", "Di", "Mi", "Do", "Fr", "Sa" };

//Month
const char* month_M[] = { "Jan", "Feb", "Mar", "Apr", "Mai", "Jun", "Jul", "Aug", "Sep", "Oct", "Nov", "Dez" };



#include "bsec.h"

// Helper functions declarations
void checkIaqSensorStatus(void);

#define SDA2 42
#define SCL2 2
#define LED_BUILTIN 41
// Create an object of the class Bsec
Bsec iaqSensor;

  
  
  int zahlen = 0;
  float temp_BME680 = 0;
  float humidity_BME680 = 0;
  float pressure_BME680 = 0;

  float co2_BME680 = 0;
  float iaq_BME680 = 0;
  float iaq_Accuracy_BME680 = 0;
    
  float staticIaq_BME680 = 0;
  float breatheVoc_BME680 = 0;
  float gas_BME680 = 0;
    
  float stability_BME680 = 0;
  float runInStatus_BME680 = 0;
    

//#define debug false

#include <WiFi.h>  
#include <SPI.h>   

#include <WiFiClientSecure.h>
#include <ArduinoJson.h>
//WiFiClient client;
//WiFiClientSecure client2;
WiFiClientSecure client;


#include <WiFiManager.h>

//Buttons
//Definitionen für Keyboard
uint8_t keyboard_val = 0;
 #define KEYPRESS_DETECTION_VALUE 1  
//Keyboard PINS ESP32-S3
  #define ROW_NUM     3 
  #define COLUMN_NUM  3 
  #define ROW1 7
  #define ROW2 15
  #define ROW3 16
  #define COL1 4
  #define COL2 5
  #define COL3 6



//Eink Mini epaper Board -> ESP32 S3
  #define E_INK_PIN_SPI_BUSY 40
  #define E_INK_PIN_SPI_CS   47
  #define E_INK_PIN_SPI_RST  39//21
  #define E_INK_PIN_SPI_DC   38
  #define E_INK_PIN_SPI_SCK  21
  #define E_INK_PIN_SPI_DIN  9
  #define E_INK_PIN_SPI_MISO 17//n/A

    long lastTrigger_SENSOR=0;
    long lastTrigger_DISPLAY=0;
    long lastTrigger_KEYS=0;
    #define UPDATERATE_SENSOR 2000
    #define UPDATERATE_DISPLAY 60000
    #define UPDATERATE_KEYS 200
    int Display_Page_Number = 0;

  
//GxEPD2_3C<GxEPD2_270c, GxEPD2_270c::HEIGHT> gfx(GxEPD2_270c(/*CS=5*/ E_INK_PIN_SPI_CS, /*DC=*/ E_INK_PIN_SPI_DC, /*RST=*/ E_INK_PIN_SPI_RST, /*BUSY=*/ E_INK_PIN_SPI_BUSY));
GxEPD2_BW<GxEPD2_270, GxEPD2_270::HEIGHT> gfx(GxEPD2_270(/*CS=5*/ E_INK_PIN_SPI_CS, /*DC=*/ E_INK_PIN_SPI_DC, /*RST=*/ E_INK_PIN_SPI_RST, /*BUSY=*/ E_INK_PIN_SPI_BUSY));

/*------------------------------------------ EINK DISPLAY TEIL--------------------------------------------------------------*/
bool LargeIcon =  true;
bool SmallIcon =  false;
int fail_counter = 0;
//#define Anzeige_42
#define Anzeige_213
#define LORA_RESET 15

#ifdef Anzeige_42
  #define Large  7
  #define Small  4
  #define xanpassung 0
  //#define weite 128 
  //#define hoehe 296
#endif
#ifdef Anzeige_213
  #define Large  5
  #define Small  4
  #define xanpassung -30
#endif



#define uS_TO_S_FACTOR 1000000UL
#define TIME_TO_SLEEP_MAX 80UL
#define TIME_TO_SLEEP_CASE1 3600UL
#define TIME_TO_SLEEP_CASE2 9000UL


void IRAM_ATTR int1Handler() {
    int1Status++;
}

void setup()
{
  WRITE_PERI_REG(RTC_CNTL_BROWN_OUT_REG, 0);//BrownOut Disable
  esp_task_wdt_init(30, false); //Task Watchdog set to 30sec
  delay(500);
  Serial.begin(115200);
  BME680_init();
  Display_Start(); //Initalisiert das Display
  delay(500);
  Serial.println("WifiManager_Start");
  wifi_manager_start();
  //wifi_start();//macht Wifi an und Basis Funktion für schnelles Connecten
  //if (init_wifi_ota()){Serial.println("Wifi aktiv");} //startet Verbindung zum Wifi
  Serial.println("Config Gyro");
  config_Gyro();
  UpdateLocalTime();
  Serial.println("setup done");
}


void loop()
{
   
   unsigned long now = millis();
   if (int1Status > 0) {
    checkForDoubleTap();
    int1Status = 0;
    Display_Data(Display_Page_Number);
   }
   if(now - lastTrigger_SENSOR > (UPDATERATE_SENSOR)){
      Measure_BME680();
      lastTrigger_SENSOR = millis();
      
   }
   if(now - lastTrigger_DISPLAY > (UPDATERATE_DISPLAY)){
      Display_Data(Display_Page_Number);
      lastTrigger_DISPLAY = millis();
      
   }
   if(now - lastTrigger_KEYS > (UPDATERATE_KEYS)){
    keyboard_val =  key_test2();
    if (keyboard_val != 0){
        Serial.println(keyboard_val);
        keyboard_val = 0;
    }
    lastTrigger_KEYS = millis();
   }  

}


void Measure_BME680(void){
  if (iaqSensor.run()) { 
    temp_BME680 = iaqSensor.temperature;
    humidity_BME680 = iaqSensor.humidity;
    pressure_BME680 = iaqSensor.pressure;

    co2_BME680 = iaqSensor.co2Equivalent;
    iaq_BME680 = iaqSensor.iaq;
    iaq_Accuracy_BME680 = iaqSensor.iaqAccuracy;
    
    staticIaq_BME680 = iaqSensor.staticIaq;
    breatheVoc_BME680 = iaqSensor.breathVocEquivalent;  
    gas_BME680 = iaqSensor.gasResistance;
    
    stability_BME680 = iaqSensor.stabStatus;
    runInStatus_BME680 = iaqSensor.runInStatus;
    Serial.print("BME680 CO2: ");Serial.println(co2_BME680);

    
    SAVE_DATA_2_RTC(pressure_BME680, &Druck_Werte);
    SAVE_DATA_2_RTC(temp_BME680, &Temp_Werte);
    SAVE_DATA_2_RTC(humidity_BME680, &Feuchte_Werte);  

    SAVE_DATA_2_RTC(co2_BME680, &CO2_Werte);
    SAVE_DATA_2_RTC(iaq_BME680, &IAQ_Werte);
    SAVE_DATA_2_RTC(staticIaq_BME680, &STATIC_IAQ_Werte);
    SAVE_DATA_2_RTC(iaq_Accuracy_BME680, &RUNIN_IAQ_Werte);

    SAVE_DATA_2_RTC(breatheVoc_BME680, &BREATHEVOC_Werte);
    SAVE_DATA_2_RTC(gas_BME680, &GAS_Werte);
    SAVE_DATA_2_RTC(stability_BME680, &STABILITY_Werte);
    SAVE_DATA_2_RTC(runInStatus_BME680, &RUNIN_Werte);
    //gasPercentage_BME680 = iaqSensor.gasPercentage;
  }
  else {
    checkIaqSensorStatus();
  }

}

void Display_Data(int Display_Page_Number){
   
   unsigned long time_trigger = millis();
   switch(Display_Page_Number){
     case 0:
        gfx.fillRect(0, 0, 180, 40, GxEPD_WHITE);
        gfx.setFont(Schrift2);
        gfx.setCursor(10, 20);
        gfx.print("- P0 - Status -");
        Verlauf_Anzeige(x, y, IconSize, &Temp_Werte, "Temp:"); // Diagramm Temp
        Verlauf_Anzeige(x, y+80, IconSize, &Feuchte_Werte, "Feuchte:"); // Feuchte Temp

        gfx.fillRect(0, 200, 180, 260, GxEPD_WHITE);
        gfx.setFont(Schrift2);
        gfx.setCursor(10, 220); gfx.print("Time:"); gfx.print(CurrentHour); gfx.print(":");gfx.print(CurrentMin); gfx.print(":");gfx.print(CurrentSec);
        gfx.setCursor(10, 240); gfx.print("Temp:"); gfx.print(temp_BME680);     
        gfx.setCursor(10, 260); gfx.print("Feuchte:"); gfx.print(humidity_BME680);     
        //gfx.setCursor(10, 260); gfx.print("Druck:"); gfx.print(pressure_BME680); 
        gfx.display(true);     
        break;
     case 1:
        gfx.fillRect(0, 0, 180, 40, GxEPD_WHITE);
        gfx.setFont(Schrift2);
        gfx.setCursor(10, 20);
        gfx.print("- P1 - CO2 -");
        Verlauf_Anzeige(x, y, IconSize, &CO2_Werte, "CO2:"); // Diagramm Temp
        Verlauf_Anzeige(x, y+80, IconSize, &IAQ_Werte, "IAQ:"); // Diagramm Temp
        
        gfx.fillRect(0, 200, 180, 260, GxEPD_WHITE);
        gfx.setFont(Schrift2);
        gfx.setCursor(10, 220); gfx.print("Time:");  gfx.print(CurrentHour); gfx.print(":");gfx.print(CurrentMin); gfx.print(":");gfx.print(CurrentSec);
        gfx.setCursor(10, 240); gfx.print("CO2:"); gfx.print(co2_BME680);     
        gfx.setCursor(10, 260); gfx.print("IAQ:"); gfx.print(iaq_BME680);     
        //gfx.setCursor(10, 260); gfx.print("Valid:"); gfx.print(iaq_Accuracy_BME680); 
        gfx.display(true);   
     break;
     case 2:
        gfx.fillRect(0, 0, 180, 40, GxEPD_WHITE);
        gfx.setCursor(10, 20);
        gfx.print("- P2 - VOC -");
        gfx.setFont(Schrift2);
        Verlauf_Anzeige(x, y, IconSize, &STATIC_IAQ_Werte, "IAQ:"); // Diagramm Temp
        Verlauf_Anzeige(x, y+80, IconSize, &BREATHEVOC_Werte, "Atem:"); // Diagramm Temp
        gfx.fillRect(0, 200, 180, 260, GxEPD_WHITE);
        gfx.setFont(Schrift2);
        gfx.setCursor(10, 220); gfx.print("Time:"); gfx.print(CurrentHour); gfx.print(":");gfx.print(CurrentMin); gfx.print(":");gfx.print(CurrentSec);
        gfx.setCursor(10, 240); gfx.print("sIAQ:"); gfx.print(staticIaq_BME680);     
        gfx.setCursor(10, 260); gfx.print("VOC:"); gfx.print(breatheVoc_BME680);     
        //gfx.setCursor(10, 260); gfx.print("GAS:"); gfx.print(gas_BME680); 
        gfx.display(true);   

     break;
     case 3:
        gfx.fillRect(0, 0, 180, 40, GxEPD_WHITE);
        gfx.setFont(Schrift2);
        gfx.setCursor(10, 20);
        gfx.print("- P3 - GAS -");
        Verlauf_Anzeige(x, y, IconSize, &RUNIN_Werte, "RUNIN:"); // Diagramm Temp
        Verlauf_Anzeige(x, y+80, IconSize, &RUNIN_IAQ_Werte, "RIAQ:"); // Diagramm 
        gfx.setFont(Schrift2);
        gfx.fillRect(0, 200, 180, 260, GxEPD_WHITE);
        //gfx.setCursor(10, 220); gfx.print("Time:"); gfx.print(CurrentHour); gfx.print(":");gfx.print(CurrentMin); gfx.print(":");gfx.print(CurrentSec);
        gfx.setCursor(10, 220); gfx.print("RIAQ:"); gfx.print(iaq_Accuracy_BME680);     
        gfx.setCursor(10, 240); gfx.print("Stability:"); gfx.print(stability_BME680);     
        gfx.setCursor(10, 260); gfx.print("RUNIN:"); gfx.print(runInStatus_BME680);     
        //gfx.setCursor(10, 260); gfx.print("GAS:"); gfx.print(gas_BME680); 
        gfx.display(true);   
     break;
     case 4:
       gfx.fillRect(0, 0, 180, 40, GxEPD_WHITE);
       gfx.setFont(Schrift2);
       gfx.setCursor(10, 20);
       gfx.print("- P4 - WIFI -");
        Verlauf_Anzeige(x, y, IconSize, &Temp_Werte, "Temp:"); // Diagramm Temp
        Verlauf_Anzeige(x, y+80, IconSize, &CO2_Werte, "CO2:"); // Diagramm 
        gfx.fillRect(0, 200, 180, 260, GxEPD_WHITE);
        gfx.setFont(Schrift2);
        gfx.setCursor(10, 220); gfx.print("Time:"); gfx.print(CurrentHour); gfx.print(":");gfx.print(CurrentMin); gfx.print(":");gfx.print(CurrentSec);
        //gfx.setCursor(10, 220); gfx.print("Stability:"); gfx.print(stability_BME680);     
        gfx.setCursor(10, 240); gfx.print("SSID:"); gfx.print(WLAN_SSID);     
        gfx.setCursor(10, 260); gfx.print("RSSI:"); gfx.print(WiFi.RSSI()); 
        gfx.display(true);  
     break;
     case 5:
       gfx.fillRect(0, 0, 180, 40, GxEPD_WHITE);
       gfx.setFont(Schrift2);
       gfx.setCursor(10, 20);
       gfx.print("- P5 - Gyro -");
        Verlauf_Anzeige(x, y, IconSize, &ROLL_Werte, "Roll:"); // Diagramm Temp
        Verlauf_Anzeige(x, y+80, IconSize, &PITCH_Werte, "Pitch:"); // Diagramm 
        gfx.fillRect(0, 200, 180, 260, GxEPD_WHITE);
        gfx.setFont(Schrift2);
        gfx.setCursor(10, 220); gfx.print("Time:"); gfx.print(CurrentHour); gfx.print(":");gfx.print(CurrentMin); gfx.print(":");gfx.print(CurrentSec);
        //gfx.setCursor(10, 220); gfx.print("Stability:"); gfx.print(stability_BME680);     
        gfx.setCursor(10, 240); gfx.print("SSID:"); gfx.print(WLAN_SSID);     
        gfx.setCursor(10, 260); gfx.print("RSSI:"); gfx.print(WiFi.RSSI()); 
        gfx.display(true);  
     break;
     default:
     break;

   }
   
}

// Helper function definitions
void checkIaqSensorStatus(void)
{
  String output;
  if (iaqSensor.status != BSEC_OK) {
    if (iaqSensor.status < BSEC_OK) {
      output = "BSEC error code : " + String(iaqSensor.status);
      Serial.println(output);
      for (;;)
        //errLeds(); /* Halt in case of failure */
        Serial.println("Defective");
    } else {
      output = "BSEC warning code : " + String(iaqSensor.status);
      Serial.println(output);
    }
  }

  if (iaqSensor.bme680Status != BME680_OK) {
    if (iaqSensor.bme680Status < BME680_OK) {
      output = "BME680 error code : " + String(iaqSensor.bme680Status);
      Serial.println(output);
      for (;;)
       // errLeds(); /* Halt in case of failure */
       Serial.println("Defective");
    } else {
      output = "BME680 warning code : " + String(iaqSensor.bme680Status);
      Serial.println(output);
    }
  }
}

void BME680_init(void){
  Wire.begin(SDA2, SCL2);

  //iaqSensor.begin(BME680_I2C_ADDR_PRIMARY, Wire);
  iaqSensor.begin(BME680_I2C_ADDR_SECONDARY, Wire);
  String output;
  output = "\nBSEC library version " + String(iaqSensor.version.major) + "." + String(iaqSensor.version.minor) + "." + String(iaqSensor.version.major_bugfix) + "." + String(iaqSensor.version.minor_bugfix);
  Serial.println(output);
  checkIaqSensorStatus();

   bsec_virtual_sensor_t sensorList[13] = {
    BSEC_OUTPUT_IAQ,
    BSEC_OUTPUT_STATIC_IAQ,
    BSEC_OUTPUT_CO2_EQUIVALENT,
    BSEC_OUTPUT_BREATH_VOC_EQUIVALENT,
    BSEC_OUTPUT_RAW_TEMPERATURE,
    BSEC_OUTPUT_RAW_PRESSURE,
    BSEC_OUTPUT_RAW_HUMIDITY,
    BSEC_OUTPUT_RAW_GAS,
    BSEC_OUTPUT_STABILIZATION_STATUS,
    BSEC_OUTPUT_RUN_IN_STATUS,
    BSEC_OUTPUT_SENSOR_HEAT_COMPENSATED_TEMPERATURE,
    BSEC_OUTPUT_SENSOR_HEAT_COMPENSATED_HUMIDITY,
    BSEC_OUTPUT_GAS_PERCENTAGE
  };

  iaqSensor.updateSubscription(sensorList, 13, BSEC_SAMPLE_RATE_LP);
  checkIaqSensorStatus();
  output = "Timestamp [ms], raw temperature [°C], pressure [hPa], raw relative humidity [%], gas [Ohm], IAQ, IAQ accuracy, temperature [°C], relative humidity [%], Static IAQ, CO2 equivalent, breath VOC equivalent";
  Serial.println(output);

}

//versucht 3 Mal eine Verbindung herzustellen. Geht dann schlafen, Wartet bei jedem Versuch 10 Sec
void retry_mechanism(void){
    delay(10000);
    fail_counter++;
    if(fail_counter < 4){
      Serial.println("Probleme ich starte nochmal einen Verbindunsgversuch");
    }
    else{
      Serial.println("Schwerwiegende Verbindungsprobleme -- 5 x Retries erfolglos");
      delay(500);
      begin_sleep();
      delay(120000);
    }
}

//Initalisiert das E-Ink Display mit den wichtigsten Grundparametern
void Display_Start(void){
  
  gfx.epd2.init(E_INK_PIN_SPI_SCK, E_INK_PIN_SPI_DIN, 115200, true, 20, false); 
  delay(100);
  gfx.setRotation(0); gfx.fillScreen(GxEPD_WHITE); gfx.setTextColor(GxEPD_BLACK);
  //gfx.fillCircle(15,70,50, GxEPD_BLACK);
  //gfx.fillRect(0, 0, 120, 80, GxEPD_BLACK);
  Serial.println("Display setup done");
  //gfx.display(false);
  //gfx.drawFastHLine(0, 115, gfx.width(), GxEPD_BLACK); //Linie horizontal Volle Breite
  gfx.setCursor(65, 90); gfx.setFont(Schrift2); 
  gfx.display(false);
  /*
    gfx.print("Wallswitch");     
    gfx.display(true);
    
    
    gfx.setCursor(10, 140); gfx.setFont(Schrift2);
    gfx.print("WiFi Check");     
    gfx.display(true);


    gfx.setCursor(10, 160); gfx.setFont(Schrift2);
    gfx.print("E-Ink Display -");     
    gfx.display(true);
  
    gfx.setCursor(10, 180); gfx.setFont(Schrift2);
    gfx.print("BME680 Test -");     
    gfx.display(true);
  */
  

}

//Grundfunktionen des Wifi, Wifi anmachen, 1. Verbindungsversuch,  Hostname setzen
void wifi_start(void){
  WiFi.setHostname("muelli");
  WiFi.mode(WIFI_STA); // WLAN auf Client setzen
  WiFi.begin(WLAN_SSID, WLAN_PASS);
  Serial.print(F("Verbinde mit "));
  Serial.println(WLAN_SSID);
  WiFi.setSleep(false); //Deaktiviert WIFI Sleep
}

void wifi_manager_start(void){
   WiFi.mode(WIFI_STA); 
    WiFiManager wm;

    // reset settings - wipe stored credentials for testing
    //wm.resetSettings();

    // Automatically connect using saved credentials,
    // if connection fails, it starts an access point with the specified name ( "AutoConnectAP"),
    // if empty will auto generate SSID, if password is blank it will be anonymous AP (wm.autoConnect())
    // then goes into a blocking loop awaiting configuration and will return success result

    bool res;
    // res = wm.autoConnect("AutoConnectAP"); // anonymous ap
    res = wm.autoConnect("AutoConnectAP","password"); // password protected ap

    if(!res) {
        Serial.println("Failed to connect");
        // ESP.restart();
    } 
    else {
        //if you get here you have connected to the WiFi    
        Serial.println("connected...yeey :)");
    }
}


// Wifi Verbindungsversuch mit Retry Mechainsmus und Energiesparen bei WLAN OFFLINE
int init_wifi_ota(void){
    WiFi.begin(WLAN_SSID, WLAN_PASS);
    delay(500);
    int wifi_retries = 0;
    Serial.println("Check ob  WLAN verbunden :-> ");
    while (WiFi.status() != WL_CONNECTED) {
        delay(135);//150 läuft besser
        wifi_retries++;        
        if (wifi_retries > 30) {
          Serial.println("2. Anlauf WLAN :-< ");
          WiFi.begin(WLAN_SSID, WLAN_PASS);
          delay(1500);
          if(WiFi.status() != WL_CONNECTED){
              Serial.println("WLAN geht gar nicht :-( ");
              /*gfx.setCursor(15, 55); gfx.println("\nWLAN ist OFF-line :-<");
              gfx.display(); delay(1800);*/
              begin_sleep();
              delay(180);
              return 0;
              delay(180);
          }
          else{
            Serial.println("2. Anlauf WLAN geht :-) ");
            return 1;
          }
       }
        
    }
    Serial.println("");
    Serial.println("WiFi connected");
    return 1;
}

void begin_sleep(){
  //gfx.sleep();
  esp_sleep_enable_timer_wakeup(UpdateInterval);
  //esp_sleep_enable_timer_wakeup(TIME_TO_SLEEP_CASE2 * uS_TO_S_FACTOR);
  Serial.print(F("Starte Dornrösschen-Schlaf.."));
  #ifdef BUILTIN_LED
    pinMode(BUILTIN_LED,INPUT);     // In case it's on, turn output off, sometimes PIN-5 on some boards is used for SPI-SS
    digitalWrite(BUILTIN_LED,HIGH); // In case it's on, turn LED off, as sometimes PIN-5 on some boards is used for SPI-SS
  #endif
  esp_deep_sleep_start();         // Sleep for e.g. 30 minutes
}
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

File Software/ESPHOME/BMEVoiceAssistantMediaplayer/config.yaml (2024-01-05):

esphome:
  name: "einklichtschalter2"
  friendly_name: EINKSCHALTER2
  on_boot: 
      - priority: 90
        then: 
        - output.turn_on: output_low

esp32:
  board: esp32-s3-devkitc-1
  framework:
    type: arduino

# Enable logging
logger:

# Enable Home Assistant API
api:
  encryption:
    key: "rzjgQVW6O5jVxWFjrWiP+C96fuSyEBiUBG5p93Z+sMA="

ota:

# Example configuration entry
psram:
  mode: octal
  speed: 80MHz

wifi:
  ssid: CHANGEME
  password: CHANGEME

  # Enable fallback hotspot (captive portal) in case wifi connection fails
  ap:
    ssid: "Esphome-Web-74E42C"
    password: "cIyFVd4Wtytm"

captive_portal:

time:
  - platform: homeassistant
    id: ntp

output:

- platform: gpio
  pin: GPIO12
  id: output_low 

# Example configuration entry
i2c:
     sda: 42
     scl: 2
     scan: true
     frequency: 400kHz

external_components:
  - source: github://neffs/esphome@bsec2_bme68x
    components: [ bme68x_bsec ]

i2s_audio:
  - id: i2s_out
    i2s_lrclk_pin: GPIO48 
    i2s_bclk_pin: GPIO13
  - id: i2s_in
    i2s_lrclk_pin: GPIO11 #WS 
    i2s_bclk_pin: GPIO10 #SCK 

microphone:
  - platform: i2s_audio
    adc_type: external
    pdm: false
    id: mic_i2s
    channel: right
    bits_per_sample: 32bit
    i2s_audio_id: i2s_in
    i2s_din_pin: GPIO14  #SD Pin from the INMP441 Microphone


media_player:
  - platform: i2s_audio
    name: "esp_speaker"
    id: media_player_speaker
    i2s_audio_id: i2s_out
    dac_type: external
    i2s_dout_pin: GPIO18   #  DIN Pin of the MAX98357A Audio Amplifier
    mode: mono

voice_assistant:
  microphone: mic_i2s
  id: va
  noise_suppression_level: 2
  auto_gain: 31dBFS
  volume_multiplier: 4.0
  use_wake_word: false
  media_player: media_player_speaker
  
  on_wake_word_detected: 
    - light.turn_on:
        id: led_light
  on_listening: 
    - light.turn_on:
        id: led_light
        effect: "Scan Effect With Custom Values"
        red: 63%
        green: 13%
        blue: 93%
  
  on_stt_end:
    - light.turn_on:
        id: led_light
        effect: "None"
        red: 0%
        green: 100%
        blue: 0%

  on_error: 
    - light.turn_on:
        id: led_light
        effect: "None"
    - if:
        condition:
          switch.is_on: use_wake_word
        then:

          - switch.turn_off: use_wake_word
          - delay: 1sec 
          - switch.turn_on: use_wake_word      
  


  on_client_connected:
    - if:
        condition:
          switch.is_on: use_wake_word
        then:
          - voice_assistant.start_continuous:

  on_client_disconnected:
    - if:
        condition:
          switch.is_on: use_wake_word
        then:
          - voice_assistant.stop:
 
  on_end:
    - light.turn_off:
        id: led_light
    
 
binary_sensor:
  - platform: status
    name: API Connection
    id: api_connection
    filters:
      - delayed_on: 1s
    on_press:
      - if:
          condition:
            switch.is_on: use_wake_word
          then:
            - voice_assistant.start_continuous:
    on_release:
      - if:
          condition:
            switch.is_on: use_wake_word
          then:
            - voice_assistant.stop:


switch:
  - platform: template
    name: Use wake word
    id: use_wake_word
    optimistic: true
    restore_mode: RESTORE_DEFAULT_ON
    entity_category: config
    on_turn_on:
      - lambda: id(va).set_use_wake_word(true);
      - if:
          condition:
            not:
              - voice_assistant.is_running
          then:
            - voice_assistant.start_continuous
    
    on_turn_off:
      - voice_assistant.stop
      - lambda: id(va).set_use_wake_word(false);

light:
  - platform: neopixelbus
    id: led_light
    type: grb
    pin: GPIO41      # DIN pin of the LED Strip
    num_leds: 9      # change the Number of LEDS according to your LED Strip.
    name: "Light"
    variant: SK6812
    default_transition_length: 0.5s
      
    effects:
      - addressable_scan:
          name: Scan Effect With Custom Values
          move_interval: 50ms
          scan_width: 2
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

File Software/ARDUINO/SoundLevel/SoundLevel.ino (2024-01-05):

/*
  https://hackaday.io/project/166867-esp32-i2s-slm
  https://github.com/ikostoski/esp32-i2s-slm
 * Display A-weighted sound level measured by I2S Microphone
 * 
 * (c)2019 Ivan Kostoski
 *
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
 * You should have received a copy of the GNU General Public License
 * along with this program.  If not, see <https://www.gnu.org/licenses/>.
 */

/*
 * Sketch samples audio data from I2S microphone, processes the data 
 * with digital IIR filters and calculates A or C weighted Equivalent 
 * Continuous Sound Level (Leq)
 * 
 * I2S is setup to sample data at Fs=48000KHz (fixed value due to 
 * design of digital IIR filters). Data is read from I2S queue 
 * in 'sample blocks' (default 125ms block, equal to 6000 samples) 
 * by 'i2s_reader_task', filtered trough two IIR filters (equalizer 
 * and weighting), summed up and pushed into 'samples_queue' as 
 * sum of squares of filtered samples. The main task then pulls data 
 * from the queue and calculates decibel value relative to microphone 
 * reference amplitude, derived from datasheet sensitivity dBFS 
 * value, number of bits in I2S data, and the reference value for 
 * which the sensitivity is specified (typically 94dB, pure sine
 * wave at 1KHz).
 * 
 * Displays line on the small OLED screen with 'short' LAeq(125ms)
 * response and numeric LAeq(1sec) dB value from the signal RMS.
 */

#include <driver/i2s.h>
#include "sos-iir-filter.h"

//
// Configuration
//

#define LEQ_PERIOD        1           // second(s)
//#define WEIGHTING         C_weighting // Also avaliable: 'C_weighting' or 'None' (Z_weighting)
#define WEIGHTING         None // Also avaliable: 'C_weighting' or 'None' (Z_weighting)
#define LEQ_UNITS         "LAeq"      // customize based on above weighting used
#define DB_UNITS          "dBA"       // customize based on above weighting used
#define USE_DISPLAY       1

// NOTE: Some microphones require at least DC-Blocker filter
#define MIC_EQUALIZER     ICS43434    // See below for defined IIR filters or set to 'None' to disable
#define MIC_OFFSET_DB     3.0103      // Default offset (sine-wave RMS vs. dBFS). Modify this value for linear calibration

// Customize these values from microphone datasheet
#define MIC_SENSITIVITY   -26         // dBFS value expected at MIC_REF_DB (Sensitivity value from datasheet)
#define MIC_REF_DB        94.0        // Value at which point sensitivity is specified in datasheet (dB)
#define MIC_OVERLOAD_DB   116.0       // dB - Acoustic overload point
#define MIC_NOISE_DB      29          // dB - Noise floor
#define MIC_BITS          24          // valid number of bits in I2S data
#define MIC_CONVERT(s)    (s >> (SAMPLE_BITS - MIC_BITS))
#define MIC_TIMING_SHIFT  0           // Set to one to fix MSB timing for some microphones, i.e. SPH0645LM4H-x

// Calculate reference amplitude value at compile time
constexpr double MIC_REF_AMPL = pow(10, double(MIC_SENSITIVITY)/20) * ((1<<(MIC_BITS-1))-1);

//
// I2S pins - Can be routed to almost any (unused) ESP32 pin.
//            SD can be any pin, inlcuding input only pins (36-39).
//            SCK (i.e. BCLK) and WS (i.e. L/R CLK) must be output capable pins
//
// Below ones are just example for my board layout, put here the pins you will use
//
#define I2S_WS            11 
#define I2S_SCK           10 
#define I2S_SD            14 

// I2S peripheral to use (0 or 1)
#define I2S_PORT          I2S_NUM_0

//
// Setup your display library (and geometry) here
// 
#if (USE_DISPLAY > 0)
  //#include <GxGDEW027W3/GxGDEW027W3.h>      // 2.7" b/w
  #include <GxEPD2_BW.h>
  #include <GxEPD2_3C.h>
  #include "GxEPD2_boards_added.h"
  //#include <Fonts/Aclonica_Regular_16.h>
  #include <Fonts/FreeMonoBold9pt7b.h>
  //const GFXfont* Schrift5 = &Aclonica_Regular_16;
  const GFXfont* Schrift2 = &FreeMonoBold9pt7b;
  #define E_INK_PIN_SPI_BUSY 40
  #define E_INK_PIN_SPI_CS   47
  #define E_INK_PIN_SPI_RST  39//21
  #define E_INK_PIN_SPI_DC   38
  #define E_INK_PIN_SPI_SCK  21
  #define E_INK_PIN_SPI_DIN  9
  #define E_INK_PIN_SPI_MISO 17//n/A
  //GxEPD2_3C<GxEPD2_270c, GxEPD2_270c::HEIGHT> gfx(GxEPD2_270c(/*CS=5*/ E_INK_PIN_SPI_CS, /*DC=*/ E_INK_PIN_SPI_DC, /*RST=*/ E_INK_PIN_SPI_RST, /*BUSY=*/ E_INK_PIN_SPI_BUSY));
  //GxEPD2_BW<GxEPD2_270, GxEPD2_270::HEIGHT> gfx(GxEPD2_270(/*CS=5*/ E_INK_PIN_SPI_CS, /*DC=*/ E_INK_PIN_SPI_DC, /*RST=*/ E_INK_PIN_SPI_RST, /*BUSY=*/ E_INK_PIN_SPI_BUSY));
  //GxEPD2_BW<GxEPD2_290, GxEPD2_290::HEIGHT> gfx(GxEPD2_290(/*CS=5*/ E_INK_PIN_SPI_CS, /*DC=*/ E_INK_PIN_SPI_DC, /*RST=*/ E_INK_PIN_SPI_RST, /*BUSY=*/ E_INK_PIN_SPI_BUSY));
  GxEPD2_BW<GxEPD2_213_B74, GxEPD2_213_B74::HEIGHT> gfx(GxEPD2_213_B74(/*CS=5*/ E_INK_PIN_SPI_CS, /*DC=*/ E_INK_PIN_SPI_DC, /*RST=*/ E_INK_PIN_SPI_RST, /*BUSY=*/ E_INK_PIN_SPI_BUSY));
#endif


//
// IIR Filters
//

// DC-Blocker filter - removes DC component from I2S data
// See: https://www.dsprelated.com/freebooks/filters/DC_Blocker.html
// a1 = -0.9992 should heavily attenuate frequencies below 10Hz
SOS_IIR_Filter DC_BLOCKER = { 
  gain: 1.0,
  sos: {{-1.0, 0.0, +0.9992, 0}}
};

// 
// Equalizer IIR filters to flatten microphone frequency response
// See respective .m file for filter design. Fs = 48Khz.
//
// Filters are represented as Second-Order Sections cascade with assumption
// that b0 and a0 are equal to 1.0 and 'gain' is applied at the last step 
// B and A coefficients were transformed with GNU Octave: 
// [sos, gain] = tf2sos(B, A)
// See: https://www.dsprelated.com/freebooks/filters/Series_Second_Order_Sections.html
// NOTE: SOS matrix 'a1' and 'a2' coefficients are negatives of tf2sos output
//

// TDK/InvenSense ICS-43434
// Datasheet: https://www.invensense.com/wp-content/uploads/2016/02/DS-000069-ICS-43434-v1.1.pdf
// B = [0.477326418836803, -0.486486982406126, -0.336455844522277, 0.234624646917202, 0.111023257388606];
// A = [1.0, -1.93073383849136326, 0.86519456089576796, 0.06442838283825100, 0.00111249298800616];
SOS_IIR_Filter ICS43434 = { 
  gain: 0.477326418836803,
  sos: { // Second-Order Sections {b1, b2, -a1, -a2}
   {+0.96986791463971267, 0.23515976355743193, -0.06681948004769928, -0.00111521990688128},
   {-1.98905931743624453, 0.98908924206960169, +1.99755331853906037, -0.99755481510122113}
  }
};

// TDK/InvenSense ICS-43432
// Datasheet: https://www.invensense.com/wp-content/uploads/2015/02/ICS-43432-data-sheet-v1.3.pdf
// B = [-0.45733702338341309   1.12228667105574775  -0.77818278904413563, 0.00968926337978037, 0.10345668405223755]
// A = [1.0, -3.3420781082912949, 4.4033694320978771, -3.0167072679918010, 1.2265536567647031, -0.2962229189311990, 0.0251085747458112]
SOS_IIR_Filter ICS43432 = {
  gain: -0.457337023383413,
  sos: { // Second-Order Sections {b1, b2, -a1, -a2}
    {-0.544047931916859, -0.248361759321800, +0.403298891662298, -0.207346186351843},
    {-1.909911869441421, +0.910830292683527, +1.790285722826743, -0.804085812369134},
    {+0.000000000000000, +0.000000000000000, +1.148493493802252, -0.150599527756651}
  }
};
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

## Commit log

2023-03-07 Changed Footprint of BME680 and Silkscreen
    [BOM.xlsx, S3-27-epaper-touch.csv, S3-27-epaper-touch.kicad_pcb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]
2023-03-08 Found a wiring Bug on the BME680
    SDA had no pinning
    wired several other lines with bigger lines
    [BOM.csv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]
2023-03-21 Bugfixes for Production
    Added a Pin Connector for a Microphone
    Fixed Bug on RV3032/RV3028 for unintended wakeup
    Removed Groove Connector due to collission with Touch Controller
    Changed Position of BME680
    [S3-27-epaper-touch.kicad_pcb, S3-27-epaper-touch.kicad_sch, bom.csv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]
2023-03-26 Reworked Int Lines of I²C Connections
    - Cleaned up Schematic
    - added Micorphone Connector
    - renamed RFM Miso Pins
    [S3-27-epaper-touch-B_Courtyard.gbr, S3-27-epaper-touch-B_Cu.gbl, S3-27-epaper-touch-B_Fab.gbr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]
2023-03-28 Added Power Sensor connector
    Addded Power Sensor ASML115
    finished for production
    [220AC-mini-C3-board-B_Cu.gbl, 220AC-mini-C3-board-B_Mask.gbs, 220AC-mini-C3-board-B_Paste.gbp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]
2023-03-28 Finished for production
    Added a dedicated Int Line for each I²C Sensor
    Added several TP (GPIO3)
    Rotated Battery Connector
    Fixed Production files
    [S3-27-epaper-touch-B_Courtyard.gbr, S3-27-epaper-touch-B_Cu.gbl, S3-27-epaper-touch-B_Fab.gbr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]
2023-03-28 Changed Screenshots and schematics

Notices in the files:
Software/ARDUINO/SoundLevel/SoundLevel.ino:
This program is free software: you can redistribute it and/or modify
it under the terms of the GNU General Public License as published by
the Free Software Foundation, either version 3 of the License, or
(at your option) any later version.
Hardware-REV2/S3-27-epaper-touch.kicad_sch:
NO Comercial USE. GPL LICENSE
